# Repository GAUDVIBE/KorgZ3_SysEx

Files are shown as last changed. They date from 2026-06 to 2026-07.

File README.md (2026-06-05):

# Korg Z3 SysEx Controller

An Arduino Mega 2560-based MIDI controller for the **Korg Z3 FM synthesizer**, allowing real-time editing of all internal FM parameters via 16 analog potentiometers, organized across 5 pages.

> The Korg Z3 only accepts complete SysEx parameter dumps — this controller handles that constraint transparently, sending a full 96-byte dump on every parameter change.

---

## Features

- **16 potentiometers × 5 pages** = up to 80 parameters mapped to the Z3's FM engine
- **Live Dump Request** — fetch the current preset directly from the Z3 over MIDI
- **Up to 8 preset slots** stored in RAM, persisted to EEPROM (survives power-off)
- **Factory preset** (SynLead) loaded on first boot
- **Pickup mode** — pots are inactive until moved, preventing value jumps on page change
- **Adaptive filtering** — exponential smoothing + proportional deadband, tuned per parameter range
- **128×32 OLED display** — shows preset name, slot index, page, and live parameter values with auto-scroll
- **4 LEDs** with distinct behaviors for navigation, dump request, and memory operations

---

## Hardware

| Component | Detail |
|---|---|
| Microcontroller | Arduino Mega 2560 |
| Potentiometers | 16× analog, pins A0–A15 |
| Button − (page prev) | Digital pin 7 |
| Button + (page next) | Digital pin 8 |
| Button cycle/save | Digital pin 5 |
| Button Dump Request | Digital pin 6 |
| LED page − | Digital pin 12 |
| LED page + | Digital pin 11 |
| LED Dump Request | Digital pin 10 |
| LED slot | Digital pin 9 |
| OLED display | 128×32 I2C, SDA=20, SCL=21, address 0x3C |

> **Tip:** Adding a 100nF ceramic capacitor between each pot's wiper and GND significantly reduces ADC noise and improves parameter stability.

### PCB / KiCad design

A full KiCad reconstruction of the board (schematic + PCB) lives in [`hardware/`](hardware/),
rebuilt from the original Gerbers. It also includes an extension: a **CD74HC4067** analog
multiplexer (extra analog input via a 6.35 mm remote-pot jack + spare channels) and **RC
anti-noise filters** (1 kΩ + 100 nF) on every analog input. See
[`hardware/RECONSTRUCTION_SCHEMA.md`](hardware/RECONSTRUCTION_SCHEMA.md) and
[`hardware/ATTRIBUTION.md`](hardware/ATTRIBUTION.md) (hardware is CC BY-NC-SA, derived from
baritonomarchetto's design).

---

## Button Behavior

| Button | Action |
|---|---|
| Pin 7 (−) | Previous page (I → V → IV → …) |
| Pin 8 (+) | Next page (I → II → … → V → I) |
| Pin 5 short press | Cycle through stored preset slots |
| Pin 5 long press ≥3s | Save current dump to memory (RAM + EEPROM) |
| Pin 6 long press ≥3s | Send Dump Request to Z3, receive and load the response |

## LED Behavior

| LED | Pin | Behavior |
|---|---|---|
| LED_PREV | 12 | Flashes 300ms on page − click |
| LED_NEXT | 11 | Flashes 300ms on page + click |
| LED_DUMP_REQ | 10 | Blinks continuously during Dump Request, off on receive/timeout |
| LED_SLOT | 9 | Solid = preset loaded from memory / Blinks 3× = save confirmed |

---

## Pages & Parameters

### Page I — Global & Levels
| Pot | Parameter | Range | SysEx offset |
|---|---|---|---|
| A0 | Algorithm | 0–7 | 13 |
| A5 | Feedback | 0–7 | 14 |
| A8 | LFO Wave | 0–3 | 15 |
| A12 | LFO Rate | 0–255 | 16 (hi) + 17 (lo) |
| A1 | PMD | 0–127 | 18 |
| A4 | PMS | 0–7 | 19 |
| A9 | AMD | 0–127 | 20 |
| A13 | AMS | 0–3 | 21 |
| A2 | M1 Wave | 0–7 | 22 |
| A6 | C1 Wave | 0–7 | 23 |
| A10 | M2 Wave | 0–7 | 24 |
| A14 | C2 Wave | 0–7 | 25 |
| A3 | M1 Level | 0–127 | 42 |
| A7 | C1 Level | 0–127 | 43 |
| A11 | M2 Level | 0–127 | 44 |
| A15 | C2 Level | 0–127 | 45 |

### Page II — Envelopes (Attack / Decay / Sustain / Decay2)
M1, C1, M2, C2 — Attack (0–31), Decay1 (0–31), Sustain (0–15), Decay2 (0–31) — offsets 46–61

### Page III — Release, EG Bias, Detune
M1, C1, M2, C2 — Release (0–15), EG Bias (0–3), Detune1 (0–7), Detune2 (0–3) — offsets 34–41, 62–65, 74–77

### Page IV — Multiply, AMS Enable, Key Scale
M1, C1, M2, C2 — Multiply1 (0–15), Multiply2 (0–15), AMS Enable (0–1), Key Scale (0–3) — offsets 26–33, 66–73

### Page V — Velocity, Keyboard Track, Reverb, Rate/op
M1, C1, M2, C2 — Velocity Int (0–15), Keyboard Track (0–15), Reverb (0–1), Rate (0–7) — offsets 78–93

---

## MIDI / SysEx Details

- **Baud rate:** 31250 (standard MIDI)
- **Dump Request:** `F0 42 30 1D 10 F7`
- **Dump header:** `F0 42 30 1D 40` + 8 bytes ASCII name + parameters + `F7`
- **Dump size:** 95–96 bytes
- **Send guard:** 300ms minimum between consecutive SysEx transmissions

### LFO Rate — 2-byte parameter
LFO Rate is the only 2-byte parameter in the Z3 dump:
- Offset 16 (hi-byte) = `val / 128` → `0x00` or `0x01`
- Offset 17 (lo-byte) = `val % 128` → `0x00`–`0x7F`

---

## EEPROM Layout

| Address | Content |
|---|---|
| 0 | Magic byte `0xA5` (initialized flag) |
| 1 | Preset count |
| 2 | Current slot index |
| 3 + n×108 | Slot n: 2B size + 10B name + 96B data |

**Total used:** 867 bytes out of 4096 available on the Mega.

---

## Filtering & Stability

The controller uses a multi-stage approach to eliminate ADC noise without sacrificing responsiveness:

1. **Exponential smoothing** — coefficient `7/8` for large ranges (≥31 values), `3/4` for small ranges
2. **Proportional deadband** — 10% of step width around each boundary, minimum 1 LSB
3. **Stability validation** — 8 consecutive identical readings required for ranges ≥127, 6 for smaller ranges
4. **Relative pickup** — on page/preset change, a pot must move ≥2 steps from its resting position before becoming active (prevents false triggers without requiring the pot to find an exact value)

---

## Libraries Required

Install via Arduino Library Manager:
- `Adafruit GFX Library`
- `Adafruit SSD1306`
- `Wire` (built-in)
- `EEPROM` (built-in)

---

## Project Background

Built around a custom board inspired by [baritonomarchetto's Arduino SysEx Patcher](https://www.instructables.com/MIDI-SysEx-Patcher-Ver2/). The Z3's FM engine requires complete parameter dumps for every edit — this controller manages that constraint internally, giving the user a seamless knob-per-function experience.

---

## License

MIT

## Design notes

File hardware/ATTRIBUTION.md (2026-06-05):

# Hardware attribution & license

The PCB in this `hardware/` folder is a **KiCad reconstruction** of the
**“MIDI SysEx Patcher Ver.2”** board designed by **baritonomarchetto**
(synthbrigade.altervista.org), reverse-engineered from the publicly shared
Gerber files since no schematic was ever published.

- Original project: <https://www.instructables.com/MIDI-SysEx-Patcher-Ver2/>
- Original repo (firmware + Gerbers): <https://github.com/baritonomarchetto/arduino-SysEx-Patcher>

## License notice (important)

- The **original hardware** (and therefore this reconstruction, which is a
  derivative work) is published by its author under **CC BY-NC-SA**
  (Attribution — NonCommercial — ShareAlike). The files in this `hardware/`
  folder are distributed under those same terms, **not** under the MIT license
  that covers the firmware in the rest of this repository.
- `firmware_CCSysEx_Patcher.ino` is the original author's firmware, included for
  reference under its **MIT** license (see `firmware_LICENSE.txt`).

## What was reconstructed / added here

- Schematic + PCB rebuilt in KiCad from the Gerbers, BOM and firmware pin-map;
  the MIDI-IN (6N138) section was confirmed by tracing the copper layers.
- **Modification v0.3** (this project's own additions): a **CD74HC4067** analog
  multiplexer (extra analog input on a 6.35 mm remote-pot jack + spare channels)
  and **RC anti-noise filters** (1 kΩ series + 100 nF to GND) on every analog input.

See `RECONSTRUCTION_SCHEMA.md` for the full details, netlist and firmware notes.

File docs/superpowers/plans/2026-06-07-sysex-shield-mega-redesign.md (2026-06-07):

# SysEx Patcher → vrai shield Mega 2560 + 3 boutons/3 LEDs — Implementation Plan

> **For agentic workers:** REQUIRED SUB-SKILL: Use superpowers:subagent-driven-development (recommended) or superpowers:executing-plans to implement this plan task-by-task. Steps use checkbox (`- [ ]`) syntax for tracking.

**Goal:** Transformer le PCB `SysEx_Patcher` (v0.9) en vrai shield enfichable Arduino Mega 2560 — embases aux positions réelles du template officiel KiCad, ajout du bloc 2×18 (D22–D53) câblé à 3 nouveaux boutons + 3 nouvelles LEDs (D22–D27), re-routage, DRC propre, Gerbers regénérés, firmware mis à jour.

**Architecture :** Approche **hybride** — un outillage Python (dans `hardware/kicad_project/shield_redesign/`) extrait la géométrie autoritaire du template KiCad `Arduino_Mega`, calcule une transformation rigide pour poser le bloc d'embases dans le repère de notre carte, puis applique des **éditions chirurgicales** sur les fichiers v0.9 (`.kicad_sch` / `.kicad_pcb`). Chaque étape est validée par un script de vérif, ERC, DRC ou rendu PNG. Re-routage via freerouting (`.dsn`→`.ses`).

**Tech Stack :** KiCad 9 (`kicad-cli`), Python 3 (parsing s-expr maison, comme le toolchain `/tmp/kgen`), freerouting (java), `gerbonara`/PIL optionnels pour rendus. Pas de dépendance pytest — les « tests » sont des scripts de vérif + ERC/DRC.

**Référence spec :** `docs/superpowers/specs/2026-06-07-sysex-shield-mega-redesign-design.md`

---

## Conventions & repères (à lire avant de commencer)

- **Projet :** `~/Documents/KorgZ3_SysEx/hardware/kicad_project/`
  - `SysEx_Patcher.kicad_pcb`, `SysEx_Patcher.kicad_sch`, `SysEx_Patcher.kicad_sym`
- **Template autoritaire :** `/Applications/KiCad/KiCad.app/Contents/SharedSupport/template/Arduino_Mega/Arduino_Mega.kicad_pcb`
- **Outils du plan :** créés dans `hardware/kicad_project/shield_redesign/` (versionnés).
- **`kicad-cli` :** `/opt/homebrew/bin/kicad-cli` (ou `/Applications/KiCad/KiCad.app/Contents/MacOS/kicad-cli`).
- **Commits :** messages en français, **sans** ligne `Co-Authored-By` (préférence utilisateur).
- **Sauvegarde de sûreté :** chaque tâche qui modifie `.kicad_pcb`/`.kicad_sch` commence par confirmer qu'un commit git propre existe (rollback possible via `git checkout`).
- **Faits géométriques établis** (repère carte v0.9, en mm) :
  - rangée analogique actuelle `y=86`, numérique `y=134` (écart 48 mm ≈ 48,26).
  - Template : rangées à `y=97.46` (analog) et `y=49.2` (digital), 2×18 (J7) origine `(193.98, 92.38)` rot 180 ; D22@pad33 `(193.98,51.74)`, D23@pad34 `(196.52,51.74)`, D24/25 `y=54.28`, D26/27 `y=56.82`.

---

## File Structure

**Créés (`hardware/kicad_project/shield_redesign/`) :**
- `sexpr.py` — mini-parseur/écrivain s-expression KiCad (lecture footprints/symbols/pads/nets, édition ciblée, ré-sérialisation sans casser le reste du fichier).
- `extract_template.py` — extrait du template la liste {ref, footprint, x, y, rot, pads[(num,signal,dx,dy)]} → `mega_geometry.json`.
- `compute_placement.py` — calcule la transformation rigide template→carte → `placement.json` (positions/rot finales de J1–J7 + J7, et table pad→net).
- `check_pinorder.py` — compare l'ordre des broches Mega de la carte au template (le contrôle clé : échoue avant, passe après).
- `apply_headers.py` — applique positions+nets des embases sur `.kicad_pcb`.
- `add_controls_sch.py` — ajoute au schéma : exposition D22–D27, J7, 3×SW/3×LED/3×R + nets.
- `place_controls_pcb.py` — pose les 7 paires bouton+LED (5 droite/2 gauche) + J7 sur le PCB.
- `render.py` — rendu PNG d'une couche pour inspection visuelle (réutilise la recette du toolchain).
- `mega_geometry.json`, `placement.json` — artefacts calculés.

**Modifiés :**
- `SysEx_Patcher.kicad_pcb`, `SysEx_Patcher.kicad_sch`, `SysEx_Patcher.kicad_sym`
- `hardware/firmware_CCSysEx_Patcher.ino`
- `hardware/RECONSTRUCTION_SCHEMA.md`

---

## Task 1 : Outillage de base — parseur s-expr + extraction template

**Files:**
- Create: `hardware/kicad_project/shield_redesign/sexpr.py`
- Create: `hardware/kicad_project/shield_redesign/extract_template.py`
- Create: `hardware/kicad_project/shield_redesign/mega_geometry.json` (généré)

- [ ] **Step 1 : Écrire le contrôle d'extraction (test)**

Create `hardware/kicad_project/shield_redesign/check_template.py` :

```python
import json, sys, pathlib
geo = json.loads(pathlib.Path("shield_redesign/mega_geometry.json").read_text())
# 7 embases attendues
refs = {h["ref"] for h in geo}
assert {"J1","J2","J3","J4","J5","J6","J7"} <= refs, f"embases manquantes: {refs}"
# tous les signaux analogiques + numériques utiles présents
sigs = {p["signal"] for h in geo for p in h["pads"]}
need = {f"A{i}" for i in range(16)} | {f"D{i}" for i in range(0,28)}
missing = need - sigs
assert not missing, f"signaux manquants: {sorted(missing)}"
# J7 = 2x18 = 36 pads
j7 = next(h for h in geo if h["ref"]=="J7")
assert len(j7["pads"]) == 36, f"J7 pads={len(j7['pads'])}"
print("check_template OK:", len(geo), "embases,", len(sigs), "signaux")
```

- [ ] **Step 2 : Lancer le contrôle → échec attendu**

Run: `cd ~/Documents/KorgZ3_SysEx/hardware/kicad_project && python3 shield_redesign/check_template.py`
Expected: FAIL (`FileNotFoundError: mega_geometry.json`) — l'artefact n'existe pas encore.

- [ ] **Step 3 : Écrire `sexpr.py` (parseur minimal)**

```python
# shield_redesign/sexpr.py — parseur/itérateur s-expression KiCad, suffisant pour extraire
# footprints/symbols et leurs (at ...) + (pad ...) + (net ...). Édition par balayage de parenthèses.
import re, math

def find_blocks(s, token):
    """Retourne (start,end) de chaque bloc équilibré commençant par `token` (ex '(footprint ')."""
    out, idx = [], 0
    while True:
        k = s.find(token, idx)
        if k < 0: break
        d, j = 0, k
        while j < len(s):
            c = s[j]
            if c == '(': d += 1
            elif c == ')':
                d -= 1
                if d == 0: break
            j += 1
        out.append((k, j+1)); idx = j+1
    return out

def block_at(b):
    m = re.search(r'\n\t\t\(at ([-\d.]+) ([-\d.]+)(?: ([-\d.]+))?\)', b) or \
        re.search(r'\(at ([-\d.]+) ([-\d.]+)(?: ([-\d.]+))?\)', b)
    return (float(m.group(1)), float(m.group(2)), float(m.group(3) or 0)) if m else None

def prop(b, name):
    m = re.search(r'"%s" "([^"]*)"' % re.escape(name), b)
    return m.group(1) if m else None

def rot(px, py, deg):
    a = math.radians(deg)
    return (px*math.cos(a) - py*math.sin(a), px*math.sin(a) + py*math.cos(a))
```

- [ ] **Step 4 : Écrire `extract_template.py`**

```python
# shield_redesign/extract_template.py
import re, json, pathlib, math
from sexpr import find_blocks, block_at, prop, rot

TPL = "/Applications/KiCad/KiCad.app/Contents/SharedSupport/template/Arduino_Mega/Arduino_Mega.kicad_pcb"
txt = pathlib.Path(TPL).read_text()
nets = {int(m.group(1)): m.group(2) for m in re.finditer(r'\(net (\d+) "([^"]*)"', txt)}

def clean(sig):  # "/A0"->"A0", "/SCL{slash}21"->"D21", "/RX0{slash}0"->"D0", "/*13"->"D13"
    if sig is None: return None
    s = sig.lstrip('/').lstrip('*')
    if "{slash}" in s:
        s = s.split("{slash}")[-1]          # garde le numéro digital
        return "D"+s if s.isdigit() else s
    if s.isdigit(): return "D"+s
    return s

out = []
for a,b in find_blocks(txt, "(footprint "):
    blk = txt[a:b]
    ref = prop(blk, "Reference")
    if ref not in {"J1","J2","J3","J4","J5","J6","J7"}: continue
    at = block_at(blk); ox,oy,orot = at
    pads = []
    for pa,pb in find_blocks(blk, "(pad "):
        pblk = blk[pa:pb]
        num = re.search(r'\(pad "([^"]*)"', pblk).group(1)
        pat = re.search(r'\(at ([-\d.]+) ([-\d.]+)', pblk)
        nm  = re.search(r'\(net (\d+)', pblk)
        sig = clean(nets.get(int(nm.group(1)),"")) if nm else None
        dx,dy = rot(float(pat.group(1)), float(pat.group(2)), orot)
        pads.append(dict(num=num, signal=sig, dx=round(dx,3), dy=round(dy,3)))
    fp = re.search(r'\(footprint "([^"]+)"', blk).group(1)
    out.append(dict(ref=ref, footprint=fp, x=ox, y=oy, rot=orot, pads=pads))

pathlib.Path("shield_redesign/mega_geometry.json").write_text(json.dumps(out, indent=1))
print("extrait:", [(h["ref"], len(h["pads"])) for h in out])
```

- [ ] **Step 5 : Générer + valider**

Run:
```
cd ~/Documents/KorgZ3_SysEx/hardware/kicad_project
python3 shield_redesign/extract_template.py
python3 shield_redesign/check_template.py
```
Expected: extraction listée (J1..J7 avec 8/10/8/8/8/8/36 pads) puis `check_template OK: 7 embases, ...`.

- [ ] **Step 6 : Commit**

```bash
cd ~/Documents/KorgZ3_SysEx
git add hardware/kicad_project/shield_redesign/
git commit -m "shield: outillage parseur s-expr + extraction géométrie template Mega"
```

---

## Task 2 : Calculer la transformation de placement (template → carte)

**Files:**
- Create: `hardware/kicad_project/shield_redesign/compute_placement.py`
- Create: `hardware/kicad_project/shield_redesign/placement.json` (généré)

**Transformation retenue (spec §3) :** miroir vertical (mettre A0–A15 côté pots, y≈86 ; numérique côté y≈134) + translation. Modèle : `Xc = sx*Xt + tx`, `Yc = -Yt + ty`, avec `sx=+1`. On cale via 2 ancres : centre de la rangée analogique template → y=86 ; centre de la rangée numérique → y=134. En x, on positionne le bloc pour que les pots gardent leur place et que le 2×18 sorte côté libre (x croissants).

- [ ] **Step 1 : Écrire le contrôle de placement**

Create `shield_redesign/check_placement.py` :

```python
import json, pathlib
P = json.loads(pathlib.Path("shield_redesign/placement.json").read_text())
heads = {h["ref"]: h for h in P["headers"]}
# rangées correctement réparties
ay = [p["y"] for p in heads["J3"]["pads_abs"]]      # A0..A7
dy = [p["y"] for p in heads["J2"]["pads_abs"]]      # D8..SCL
assert abs(sum(ay)/len(ay) - 86) < 3, f"rangée analog mal calée: {sum(ay)/len(ay)}"
assert abs(sum(dy)/len(dy) - 134) < 3, f"rangée digit mal calée: {sum(dy)/len(dy)}"
# 2x18 (J7) dans l'outline carte (x<170, y dans [40,180]) — bornes à ajuster selon outline réelle
j7 = heads["J7"]["pads_abs"]
xs = [p["x"] for p in j7]; ys = [p["y"] for p in j7]
assert max(xs) < 172 and min(xs) > 0, f"J7 hors X: {min(xs)}..{max(xs)}"
print("check_placement OK — analogY=%.1f digitY=%.1f J7x=%.1f..%.1f"%(
      sum(ay)/len(ay), sum(dy)/len(dy), min(xs), max(xs)))
```

- [ ] **Step 2 : Lancer → échec attendu**

Run: `python3 shield_redesign/check_placement.py`
Expected: FAIL (`FileNotFoundError: placement.json`).

- [ ] **Step 3 : Écrire `compute_placement.py`**

```python
# shield_redesign/compute_placement.py
import json, pathlib
geo = json.loads(pathlib.Path("shield_redesign/mega_geometry.json").read_text())

# centres de rangée dans le template (y) :
tpl_analog_y = 97.46      # J1/J3/J5
tpl_digit_y  = 49.20      # J2/J4/J6
CARD_ANALOG_Y = 86.0
CARD_DIGIT_Y  = 134.0
# miroir vertical: Yc = -Yt + ty.  Caler analog: -97.46 + ty = 86 -> ty = 183.46
TY = CARD_ANALOG_Y + tpl_analog_y
# vérif digit: -49.20 + 183.46 = 134.26 ~ 134  (cohérent, l'écart 48.26 est respecté)
# en x: décaler pour que A0 (~x150.8 template) retombe près des pots. Les pots occupent x~30..120.
# On vise A0 ~ x=72 (comme l'ancienne carte). A0 template x=150.8 -> TX = 72 - 150.8 = -78.8
TX = 72.0 - 150.80

def xf(x,y): return (x + TX, -y + TY)

headers=[]
for h in geo:
    fx,fy = xf(h["x"], h["y"])
    # rotation finale: miroir vertical => rot' = -rot (mod 360) ; pads recalculés via xf sur abs
    pads_abs=[]
    for p in h["pads"]:
        ax,ay = h["x"]+p["dx"], h["y"]+p["dy"]
        cx,cy = xf(ax,ay)
        pads_abs.append(dict(num=p["num"], signal=p["signal"], x=round(cx,3), y=round(cy,3)))
    headers.append(dict(ref=h["ref"], footprint=h["footprint"],
                        x=round(fx,3), y=round(fy,3), rot=(-h["rot"])%360,
                        pads_abs=pads_abs))

# table signal->(ref,padnum,x,y) pour le mapping net plus tard
sigmap={}
for h in headers:
    for p in h["pads_abs"]:
        if p["signal"]: sigmap.setdefault(p["signal"], []).append(
            dict(ref=h["ref"], pad=p["num"], x=p["x"], y=p["y"]))

pathlib.Path("shield_redesign/placement.json").write_text(
    json.dumps(dict(headers=headers, sigmap=sigmap, TX=TX, TY=TY), indent=1))
print("placement calculé — TX=%.2f TY=%.2f"%(TX,TY))
```

- [ ] **Step 4 : Générer + valider**

Run:
```
python3 shield_redesign/compute_placement.py
python3 shield_redesign/check_placement.py
```
Expected: `check_placement OK — analogY≈86 digitY≈134 J7x=...`. Si `J7 hors X`, ajuster `TX`/orientation et relancer (le 2×18 doit tomber dans l'outline ; sinon poser J7 séparément côté libre — voir Task 4).

- [ ] **Step 5 : Rendu de contrôle (positions sur fond carte)**

Create `shield_redesign/render.py` (rendu d'une couche PCB en PNG) :

```python
import subprocess, sys
PCB="SysEx_Patcher.kicad_pcb"; OUT=sys.argv[1] if len(sys.argv)>1 else "/tmp/board.png"
KCLI="/opt/homebrew/bin/kicad-cli"
# export SVG de F.Cu + B.Cu + silk + edge, puis png
subprocess.run([KCLI,"pcb","render","-o",OUT,"--side","top",PCB], check=False)
print("rendu:",OUT)
```

Run: `python3 shield_redesign/render.py /tmp/board_before.png` (référence visuelle avant édition).
Expected: PNG généré (état v0.9 actuel) — sert de comparaison.

- [ ] **Step 6 : Commit**

```bash
git add hardware/kicad_project/shield_redesign/
git commit -m "shield: transformation de placement template->carte + contrôles"
```

---

## Task 3 : Appliquer les positions+nets des embases Mega sur le PCB

**Files:**
- Create: `hardware/kicad_project/shield_redesign/apply_headers.py`
- Create: `hardware/kicad_project/shield_redesign/check_pinorder.py`
- Modify: `SysEx_Patcher.kicad_pcb` (footprints JMA1-3/JMD1-4 repositionnés ; J7 ajouté)

**Note de mapping :** les empreintes actuelles (`JMA1..3`, `JMD1..4`) sont des `1xNN`. Le template
utilise `J1..J7` avec un découpage différent. Stratégie : **conserver les refs existantes** et
**réécrire leur `(at ...)` + l'ordre des nets de pads** pour reproduire la séquence de signaux du
template sur chaque rangée, puis **ajouter J7 (2×18)**. (Si le re-découpage 1×8/1×10 ne coïncide pas,
remplacer les strips par des empreintes calquées sur J1..J6 du template — décision prise à l'exécution
selon `placement.json`.)

- [ ] **Step 1 : Écrire le contrôle d'ordre des broches**

Create `shield_redesign/check_pinorder.py` :

```python
import re, json, pathlib
from sexpr import find_blocks, prop, block_at, rot
PCB = pathlib.Path("SysEx_Patcher.kicad_pcb").read_text()
nets = {int(m.group(1)): m.group(2) for m in re.finditer(r'\(net (\d+) "([^"]*)"', PCB)}
# ordre attendu (template, x croissants) sur la rangée analogique
EXPECT_ANALOG = ["A7","A6","A5","A4","A3","A2","A1","A0","A15","A14","A13","A12","A11","A10","A9","A8"]
pts=[]
for a,b in find_blocks(PCB,"(footprint "):
    blk=PCB[a:b]; ref=prop(blk,"Reference")
    if not ref or not ref.startswith(("JMA","JMD","J7")): continue
    ox,oy,orot=block_at(blk)
    for pa,pb in find_blocks(blk,"(pad "):
        pblk=blk[pa:pb]
        nm=re.search(r'\(net (\d+)',pblk); sig=nets.get(int(nm.group(1)),"") if nm else ""
        pat=re.search(r'\(at ([-\d.]+) ([-\d.]+)',pblk)
        dx,dy=rot(float(pat.group(1)),float(pat.group(2)),orot)
        pts.append((round(oy+dy), round(ox+dx,1), sig))
# rangée analogique = y le plus proche de 86
ays=[p for p in pts if abs(p[0]-86)<4 and p[2].startswith("A")]
order=[s for _,_,s in sorted(ays)]
assert order==EXPECT_ANALOG, f"ordre analog non conforme:\n got {order}\n exp {EXPECT_ANALOG}"
print("check_pinorder OK — rangée analogique conforme au Mega réel")
```

- [ ] **Step 2 : Lancer → échec attendu (état v0.9)**

Run: `python3 shield_redesign/check_pinorder.py`
Expected: FAIL — l'ordre actuel est `A0 A1 … A15` (monotone), pas l'ordre Mega. Confirme le besoin.

- [ ] **Step 3 : Sauvegarde + écrire `apply_headers.py`**

Confirmer working tree propre : `git status --porcelain` (vide attendu).
`apply_headers.py` lit `placement.json`, et pour chaque embase :
- met à jour le `(at x y rot)` du footprint,
- réassigne, pad par pad, le `(net id "signal")` selon `pads_abs[*].signal` (résoudre l'id net via la table `(net ...)` du fichier, créer le net s'il manque — ex. D22–D27),
- ajoute le bloc footprint `J7` (PinSocket_2x18) copié depuis le template, transformé, avec nets D22–D53/+5V/GND.

```python
# shield_redesign/apply_headers.py  (squelette — logique d'édition ciblée)
import re, json, pathlib
from sexpr import find_blocks, prop
P = json.loads(pathlib.Path("shield_redesign/placement.json").read_text())
src = pathlib.Path("SysEx_Patcher.kicad_pcb").read_text()

# 1) index nets existants + helper d'ajout
net_ids = {m.group(2): int(m.group(1)) for m in re.finditer(r'\(net (\d+) "([^"]*)"', src)}
next_id = max(net_ids.values())+1
def ensure_net(name):
    global next_id, src
    if name not in net_ids:
        net_ids[name]=next_id
        # insérer la déclaration (net N "name") après la dernière
        src = re.sub(r'(\n\t\(net \d+ "[^"]*"\)\n)(?!\t\(net)',
                     r'\1\t(net %d "%s")\n'%(next_id,name), src, count=1)
        next_id+=1
    return net_ids[name]

# 2) pour chaque header de placement.json : réécrire (at ...) + nets des pads (édition par ref+pad)
#    (implémentation détaillée à l'exécution : repérer le bloc footprint par "Reference" "<ref>",
#     remplacer son (at ...), puis pour chaque (pad "num" ...) remplacer le (net ...) par ensure_net(signal))
# 3) ajouter le footprint J7 depuis le template (string transformé) avant la 1re ligne (gr_ ...) finale.

pathlib.Path("SysEx_Patcher.kicad_pcb").write_text(src)
print("apply_headers: embases repositionnées + J7 ajouté")
```

> À l'exécution : implémenter le remplacement pad-par-pad (les `(pad "n" ... (net ...))` sont identifiés
> dans le bloc du footprint par leur numéro). Tester sur une copie d'abord (`cp` → éditer → diff).

- [ ] **Step 4 : Appliquer + valider l'ordre + ERC structure**

Run:
```
python3 shield_redesign/apply_headers.py
python3 shield_redesign/check_pinorder.py
/opt/homebrew/bin/kicad-cli pcb drc --severity-error SysEx_Patcher.kicad_pcb -o /tmp/drc_headers.json || true
```
Expected: `check_pinorder OK`. Le DRC aura des **erreurs de routage** (pistes Mega désormais incohérentes) — **attendu** à ce stade, corrigé en Task 7. Vérifier seulement qu'il n'y a pas d'erreur de *footprint cassé* (parsing OK).

- [ ] **Step 5 : Rendu de contrôle**

Run: `python3 shield_redesign/render.py /tmp/board_headers.png`
Inspecter : embases Mega aux nouvelles positions, J7 visible côté libre, pas de chevauchement d'empreintes avec les pots.

- [ ] **Step 6 : Commit**

```bash
git add hardware/kicad_project/SysEx_Patcher.kicad_pcb hardware/kicad_project/shield_redesign/
git commit -m "shield: embases Mega aux positions réelles du template + bloc 2x18 (J7)"
```

---

## Task 4 : Schéma — exposer D22–D27 + ajouter J7, 3×SW, 3×LED, 3×R

**Files:**
- Modify: `SysEx_Patcher.kicad_sym` (symbole Mega : ajouter pins D22–D27) ou nouveau symbole 2×18
- Modify: `SysEx_Patcher.kicad_sch`
- Create: `hardware/kicad_project/shield_redesign/add_controls_sch.py`

- [ ] **Step 1 : Écrire le contrôle de netlist schéma**

Create `shield_redesign/check_sch_nets.py` :

```python
import re, pathlib
sch = pathlib.Path("SysEx_Patcher.kicad_sch").read_text()
# labels D22..D27 présents
for n in range(22,28):
    assert re.search(r'"D%d"'%n, sch), f"net D%d absent du schéma"%n
# 3 nouveaux SW, 3 LED, 3 R (réfs attendues)
for ref in ["SW5","SW6","SW7","R28","R29","R30"]:
    assert re.search(r'"Reference" "%s"'%ref, sch), f"{ref} absent"
print("check_sch_nets OK — D22..D27 + SW5-7 + R28-30 présents")
```

- [ ] **Step 2 : Lancer → échec attendu**

Run: `python3 shield_redesign/check_sch_nets.py`
Expected: FAIL (`net D22 absent`).

- [ ] **Step 3 : Étendre le symbole Mega (D22–D27)**

Dans `SysEx_Patcher.kicad_sch`, le symbole `SysEx_Patcher:Arduino_Mega2560` a 35 pins (n°1–35).
Ajouter 6 pins (n°36–41) nommées `D22`,`D23`,`D24`,`D25`,`D26`,`D27`, type `passive`, espacées de
2,54 mm sous le pin 35, dupliquées dans les deux blocs `_0_1`/`_1_1` comme les autres pins. (Voir la
forme exacte d'une pin existante autour de la ligne du pin `D13` pour calquer le format.)

- [ ] **Step 4 : Écrire `add_controls_sch.py`**

Ajoute au schéma (dans une zone libre, ex. sous la colonne boutons existante) :
- 3× `Switch:SW_Push` (`SW5`,`SW6`,`SW7`) : pin1 → label `D22`/`D24`/`D26`, pin2 → `GND` (power symbol).
- 3× `Device:LED` + 3× `Device:R` `1k` (`R28`,`R29`,`R30`) : net Mega `D23`/`D25`/`D27` → R → LED anode, cathode → `GND`.
- Câbler le pin Mega D22–D27 correspondant (fil + label de net identique : `D22`…`D27`).
- Empreintes : SW `Button_Switch_THT:SW_PUSH_6mm`, LED `LED_THT:LED_D3.0mm`, R `Resistor_THT:R_Axial_DIN0207_L6.3mm_D2.5mm_P10.16mm_Horizontal`.

Modèle d'un bloc bouton (à répliquer ×3 avec coords/nets différents) — reprendre le format exact d'un
`SW_Push` existant du fichier (ex. `SW2`) :

```
(symbol (lib_id "Switch:SW_Push")(at <X> <Y> 0)(unit 1)
  (property "Reference" "SW5" ...)(property "Value" "SW" ...)
  (property "Footprint" "Button_Switch_THT:SW_PUSH_6mm" ...)
  (instances (project "SysEx_Patcher" (path "/" (reference "SW5")(unit 1)))))
(label "D22" (at <Xpin1> <Ypin1> 0) ...)
(symbol (lib_id "power:GND") (at <Xpin2> <Ypin2> 0) ...)   # ou fil vers un GND existant
```

- [ ] **Step 5 : Appliquer + ERC**

Run:
```
python3 shield_redesign/add_controls_sch.py
python3 shield_redesign/check_sch_nets.py
/opt/homebrew/bin/kicad-cli sch erc SysEx_Patcher.kicad_sch -o /tmp/erc.rpt --severity-error || true
```
Expected: `check_sch_nets OK`. ERC : **0 erreur** (pins non connectées des nouveaux composants = aucune ; D28–D53 de J7 peuvent générer des warnings « unconnected » → poser des flags `no_connect` dessus si J7 est dans le schéma, ou laisser J7 uniquement côté PCB et exposer D22–D27 via le symbole Mega — choisir l'option qui donne ERC propre).

- [ ] **Step 6 : Commit**

```bash
git add hardware/kicad_project/SysEx_Patcher.kicad_sch hardware/kicad_project/SysEx_Patcher.kicad_sym hardware/kicad_project/shield_redesign/
git commit -m "shield: schéma — D22-D27 exposés, J7 + 3 boutons/3 LEDs/3 R ajoutés"
```

---

## Task 5 : Placer les 7 paires bouton+LED sur le PCB (5 droite / 2 gauche)

**Files:**
- Create: `hardware/kicad_project/shield_redesign/place_controls_pcb.py`
- Modify: `SysEx_Patcher.kicad_pcb`

- [ ] **Step 1 : Écrire le contrôle de placement des contrôles**

Create `shield_redesign/check_controls_pcb.py` :

```python
import re, pathlib
from sexpr import find_blocks, prop, block_at
PCB = pathlib.Path("SysEx_Patcher.kicad_pcb").read_text()
pos={}
for a,b in find_blocks(PCB,"(footprint "):
    blk=PCB[a:b]; ref=prop(blk,"Reference")
    if ref and (ref.startswith("SW") or ref.startswith("D") or ref.startswith("LED")):
        at=block_at(blk); pos[ref]=(at[0],at[1])
# 7 boutons présents
sws=[r for r in pos if r.startswith("SW")]
assert len(sws)>=7, f"boutons trouvés: {sws}"
# grille pots ~ x 30..120 ; 5 boutons à droite (x>125), 2 à gauche (x<25)
xs=[pos[r][0] for r in sws]
right=[x for x in xs if x>120]; left=[x for x in xs if x<28]
assert len(right)>=5 and len(left)>=2, f"répartition D/G incorrecte: droite={len(right)} gauche={len(left)}"
print("check_controls_pcb OK — %d boutons (droite %d / gauche %d)"%(len(sws),len(right),len(left)))
```

- [ ] **Step 2 : Lancer → échec attendu**

Run: `python3 shield_redesign/check_controls_pcb.py`
Expected: FAIL — les 3 nouveaux SW/LED ne sont pas encore placés (footprints à (0,0) après import schéma, ou absents). Répartition non satisfaite.

- [ ] **Step 3 : Synchroniser schéma→PCB (importer les nouveaux composants)**

Mettre à jour le PCB depuis le schéma pour matérialiser SW5-7, R28-30, LED (et J7 si géré côté sch).
Comme l'édition est scriptée, `place_controls_pcb.py` **ajoute directement** les footprints manquants
(copiés sur le format d'un `SW_PUSH_6mm`/`LED_D3.0mm`/`R_Axial` existant) avec leurs nets.

- [ ] **Step 4 : Écrire `place_controls_pcb.py`**

Pose les coordonnées (repère carte) :
- **5 paires à droite** des pots : colonne à `x≈150`, `y = 60,84,108,132,156` ; LED à `x≈158` en regard.
- **2 paires à gauche** : colonne à `x≈18`, `y = 84,132` ; LED à `x≈10` en regard.
- Affecter : boutons existants `SW?`(D5-D8) + nouveaux `SW5-7`(D22/24/26) répartis sur les 7 slots ;
  LEDs existantes (D9-D12) + nouvelles (D23/25/27) chacune à côté de son bouton.
- Sérigraphie : numéro/fonction à côté de chaque paire (reprendre le style `gr_text` existant).

```python
# shield_redesign/place_controls_pcb.py (squelette)
import pathlib
SLOTS_RIGHT=[(150,60),(150,84),(150,108),(150,132),(150,156)]
SLOTS_LEFT =[(18,84),(18,132)]
# mapping slot -> (bouton_ref, led_ref) ; à figer à l'exécution selon refs réelles existantes
# pour chaque: réécrire (at ...) du footprint bouton à SLOT, et de la LED à SLOT±8mm en x.
print("place_controls_pcb: 7 paires posées (5 droite / 2 gauche)")
```

- [ ] **Step 5 : Valider + rendu**

Run:
```
python3 shield_redesign/place_controls_pcb.py
python3 shield_redesign/check_controls_pcb.py
python3 shield_redesign/render.py /tmp/board_controls.png
```
Expected: `check_controls_pcb OK — 7 boutons (droite 5 / gauche 2)`. Rendu : 7 paires bouton+LED bien réparties, chaque LED jouxtant son bouton, pas de collision avec pots/embases/J7.

- [ ] **Step 6 : Commit**

```bash
git add hardware/kicad_project/SysEx_Patcher.kicad_pcb hardware/kicad_project/shield_redesign/
git commit -m "shield: placement des 7 paires bouton+LED (5 droite / 2 gauche)"
```

---

## Task 6 : Re-router (freerouting) + DRC propre

**Files:**
- Modify: `SysEx_Patcher.kicad_pcb` (routage)
- Use: `/tmp/kgen` workflow `.dsn`→freerouting→`.ses`

- [ ] **Step 1 : Écrire le contrôle DRC**

Create `shield_redesign/check_drc.py` :

```python
import json, subprocess, sys, pathlib
KCLI="/opt/homebrew/bin/kicad-cli"
subprocess.run([KCLI,"pcb","drc","--severity-error","--format","json",
                "-o","/tmp/drc.json","SysEx_Patcher.kicad_pcb"], check=False)
d=json.loads(pathlib.Path("/tmp/drc.json").read_text())
viol=d.get("violations",[])
unrouted=[v for v in viol if "unconnected" in v.get("type","")]
print("DRC: %d violations (%d unconnected)"%(len(viol),len(unrouted)))
assert len(viol)==0, "DRC non propre — voir /tmp/drc.json"
print("check_drc OK — 0 violation")
```

- [ ] **Step 2 : Lancer → échec attendu (avant routage)**

Run: `python3 shield_redesign/check_drc.py`
Expected: FAIL — nombreuses violations `unconnected` (pistes Mega rippées + nouveaux nets). Confirme le besoin de re-router.

- [ ] **Step 3 : Rip-up des pistes Mega + export DSN**

Supprimer du `.kicad_pcb` les segments/vias devenus incohérents (pistes attachées aux anciennes
positions de pads Mega). Approche scriptée : retirer les `(segment ...)`/`(via ...)` dont un extrémité
ne tombe plus sur un pad de net correspondant — ou plus simple/robuste : **rip-up complet** puis
re-route global. Exporter le DSN :

```
/opt/homebrew/bin/kicad-cli pcb export specctra SysEx_Patcher.kicad_pcb -o /tmp/kgen/board_shield.dsn
```

- [ ] **Step 4 : Freerouting (plusieurs passes)**

```
java -jar <freerouting.jar> -de /tmp/kgen/board_shield.dsn -do /tmp/kgen/board_shield.ses -mp 100
```
(réutiliser le jar et les options qui ont servi à router v0.9 ; itérer `-mp`/passes jusqu'à 100 %).
Importer la session :
```
/opt/homebrew/bin/kicad-cli pcb import specctra /tmp/kgen/board_shield.ses SysEx_Patcher.kicad_pcb
```

- [ ] **Step 5 : DRC jusqu'à 0**

Run: `python3 shield_redesign/check_drc.py`
Expected: `check_drc OK — 0 violation`. Sinon : itérer (déplacer un composant gênant, relancer freerouting). Re-rendre `render.py` pour inspecter.

- [ ] **Step 6 : Commit**

```bash
git add hardware/kicad_project/SysEx_Patcher.kicad_pcb
git commit -m "shield: re-routage complet (freerouting) — DRC 0 violation"
```

---

## Task 7 : Regénérer les Gerbers

**Files:**
- Modify: `hardware/fab/*` (Gerbers + drill + zip)

- [ ] **Step 1 : Écrire le contrôle Gerbers**

Create `shield_redesign/check_gerbers.py` :

```python
import pathlib, zipfile
fab=pathlib.Path("../fab")
need=["-F_Cu.gtl","-B_Cu.gbl","-In1_Cu.g1","-In2_Cu.g2","-Edge_Cuts.gm1",".drl"]
got=[p.name for p in fab.iterdir()]
for suf in need:
    assert any(n.endswith(suf) for n in got), f"Gerber manquant: {suf}"
z=fab/"SysEx_Patcher_GERBERS.zip"
assert z.exists() and zipfile.ZipFile(z).namelist(), "zip fab vide/absent"
print("check_gerbers OK —", len(got), "fichiers fab")
```

- [ ] **Step 2 : Lancer (référence) puis regénérer**

Run (référence avant) : `cd ~/Documents/KorgZ3_SysEx/hardware/kicad_project && python3 shield_redesign/check_gerbers.py` → OK (anciens Gerbers). On les **remplace** :

```
KCLI=/opt/homebrew/bin/kicad-cli
$KCLI pcb export gerbers -o ../fab/ SysEx_Patcher.kicad_pcb
$KCLI pcb export drill   -o ../fab/ SysEx_Patcher.kicad_pcb
cd ../fab && rm -f SysEx_Patcher_GERBERS.zip && zip SysEx_Patcher_GERBERS.zip SysEx_Patcher-*.* SysEx_Patcher.drl && cd -
```

- [ ] **Step 3 : Valider**

Run: `python3 shield_redesign/check_gerbers.py`
Expected: `check_gerbers OK`. Vérifier la date des fichiers (récents) + ouvrir un rendu Gerber (optionnel `render.py`).

- [ ] **Step 4 : Commit**

```bash
git add hardware/fab/
git commit -m "shield: regénération des Gerbers (fab) après redesign shield"
```

---

## Task 8 : Mettre à jour le firmware

**Files:**
- Modify: `hardware/firmware_CCSysEx_Patcher.ino`

- [ ] **Step 1 : Écrire le contrôle firmware (grep)**

Create `shield_redesign/check_fw.py` :

```python
import pathlib, re
fw=pathlib.Path("../firmware_CCSysEx_Patcher.ino").read_text()
assert "butLayout2" in fw and "{22, 24, 26}" in fw.replace(" ",""), "butLayout2 absent/incorrect" or True
assert "LEDLayout2" in fw and "{23, 25, 27}" in fw.replace(" ",""), "LEDLayout2 absent/incorrect" or True
print("check_fw OK — butLayout2/LEDLayout2 présents")
```
(Note : ajuster la comparaison d'espaces ; l'essentiel est la présence des deux tableaux avec les bons pins.)

- [ ] **Step 2 : Lancer → échec attendu**

Run: `python3 shield_redesign/check_fw.py`
Expected: FAIL (`butLayout2 absent`).

- [ ] **Step 3 : Éditer le firmware**

Ajouter près de `butLayout[]`/`LEDLayout[]` :

```c
const byte butLayout2[3] = {22, 24, 26};   // 3 nouveaux boutons (INPUT_PULLUP)
const byte LEDLayout2[3] = {23, 25, 27};   // 3 nouvelles LEDs (OUTPUT)
```
Dans `setup()` : `for(byte b:butLayout2) pinMode(b,INPUT_PULLUP); for(byte l:LEDLayout2) pinMode(l,OUTPUT);`
Dans la boucle de lecture/écriture : répliquer la logique des boutons/LEDs existants sur ces tableaux.

- [ ] **Step 4 : Valider (compilation si arduino-cli dispo, sinon grep)**

Run: `python3 shield_redesign/check_fw.py`
Expected: `check_fw OK`. Si `arduino-cli` présent : `arduino-cli compile --fqbn arduino:avr:mega ../firmware_CCSysEx_Patcher.ino` → compile sans erreur (sinon, vérif manuelle de la syntaxe).

- [ ] **Step 5 : Commit**

```bash
git add hardware/firmware_CCSysEx_Patcher.ino hardware/kicad_project/shield_redesign/
git commit -m "shield: firmware — lecture 3 boutons + pilotage 3 LEDs (D22-D27)"
```

---

## Task 9 : Documentation + vérification finale

**Files:**
- Modify: `hardware/RECONSTRUCTION_SCHEMA.md`
- Update: mémoire `sysex-patcher-kicad.md` (index `MEMORY.md`)

- [ ] **Step 1 : Mettre à jour `RECONSTRUCTION_SCHEMA.md`**

Ajouter une section « MODIFICATION v1.0 — vrai shield Mega + 7 boutons/7 LEDs » décrivant : embases aux
positions réelles du template KiCad, bloc 2×18, D22–D27 → 3 boutons/3 LEDs, re-routage, Gerbers v1.0.

- [ ] **Step 2 : Vérification d'ensemble (tous les contrôles)**

Run:
```
cd ~/Documents/KorgZ3_SysEx/hardware/kicad_project
for c in check_template check_placement check_pinorder check_controls_pcb check_drc check_gerbers; do
  echo "== $c =="; python3 shield_redesign/$c.py || echo "ÉCHEC $c"
done
python3 shield_redesign/check_fw.py
```
Expected: tous `OK`, DRC 0 violation, Gerbers présents.

- [ ] **Step 3 : Rendu final + test-fit rappel**

Run: `python3 shield_redesign/render.py /tmp/board_final.png` ; comparer à `/tmp/board_before.png`.
Rappel à consigner : **test-fit sur Mega réel avant commande fab** (positions issues du template, à confirmer mécaniquement).

- [ ] **Step 4 : Mettre à jour la mémoire**

Mettre à jour `/Users/gaudry/.claude/projects/-Users-gaudry/memory/sysex-patcher-kicad.md` (passage en vrai shield + 7/7 contrôles) et la ligne d'index dans `MEMORY.md`.

- [ ] **Step 5 : Commit final**

```bash
cd ~/Documents/KorgZ3_SysEx
git add hardware/RECONSTRUCTION_SCHEMA.md
git commit -m "shield: doc v1.0 — vrai shield Mega + 7 boutons/7 LEDs"
```

---

## Self-Review (couverture spec)

- §1 objectif/périmètre → Tasks 3–8 (embases réelles, 2×18, 3+3 contrôles, garde l'allure). ✓
- §2 hybride → outillage Tasks 1–2 (calcul depuis template) + éditions chirurgicales Tasks 3–5. ✓
- §3 géométrie embases + 2×18 → Tasks 1 (extraction), 2 (transform), 3 (application + `check_pinorder`). ✓
- §4 boutons/LEDs 7+7, 5 droite/2 gauche, D22/24/26 + D23/25/27, 1k → Tasks 4 (schéma) + 5 (placement, `check_controls_pcb`). ✓
- §5 schéma (exposer D22–D27, J7, no-connect D28–D53) → Task 4. ✓
- §6 routage + DRC + Gerbers + firmware → Tasks 6, 7, 8. ✓
- §7 risques (routage, encombrement, fab) → Task 6 (itérations DRC), rendus Tasks 2/3/5/9, rappel test-fit Task 9. ✓
- §8 critères de succès → vérif d'ensemble Task 9. ✓

**Notes d'exécution :** plusieurs `apply_*.py` ont un squelette dont le détail d'édition s-expr (remplacement pad-par-pad, copie du bloc J7) se finalise à l'exécution sur les fichiers réels — toujours travailler sur copie + `git diff` avant commit, et s'appuyer sur les `check_*.py` comme garde-fous.

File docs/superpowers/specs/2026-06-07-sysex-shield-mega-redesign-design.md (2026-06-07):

# Design — SysEx Patcher : passage en vrai shield Arduino Mega 2560 + 3 boutons / 3 LEDs

> Date : 2026-06-07 · Projet : `KorgZ3_SysEx/hardware/kicad_project/SysEx_Patcher` (rev actuelle v0.9)
> Statut : design validé, prêt pour plan d'implémentation.

## 1. Objectif & périmètre

Transformer le PCB `SysEx_Patcher` en **vrai shield enfichable Arduino Mega 2560** : replacer toutes
les embases Mega aux **positions physiques réelles** (issues du template officiel KiCad `Arduino_Mega`),
ajouter le **bloc 2×18 (D22–D53)**, et y câbler **3 nouveaux boutons + 3 nouvelles LEDs** (D22–D27).
On **garde l'allure actuelle** : outline ~172×172 mm, grille 4×4 de 16 pots, MIDI IN/OUT (DIN-5),
jack 6,35 déporté, OLED, jack DC, mux 4067 + filtres RC — tous conservés.

**Hors périmètre :** redesign compact, réduction de la carte à l'empreinte Mega, refonte du firmware
au-delà de l'ajout des 3 boutons/3 LEDs, ajout de trous de fixation Mega ou de stacking headers
(mécanique laissée « minimale », gérée par l'utilisateur).

### Pourquoi ce redesign

La carte v0.9 **ne s'enfiche pas** sur un Mega réel : l'ordre physique des broches sur ses embases ne
correspond pas à celui d'un Arduino Mega 2560 (vérifié contre le template officiel KiCad — ni en direct,
ni en miroir). Elle se reliait donc au Mega par fils. Ce redesign corrige cela en adoptant la géométrie
réelle du template, rendant la carte compatible broche-à-broche.

```
Analogique (x croissants) — vrai Mega : A7 A6 A5 A4 A3 A2 A1 A0 | A15 A14 … A9 A8
                              v0.9      : A0 A1 A2 A3 A4 A5 A6 A7 A8 … A15  (monotone, NON conforme)
```

## 2. Approche d'exécution : hybride (C)

1. **Calculer** la géométrie autoritaire depuis le template officiel KiCad
   `/Applications/KiCad/KiCad.app/Contents/SharedSupport/template/Arduino_Mega/Arduino_Mega.kicad_pcb`
   (positions des embases J1–J7, mapping pad→net) + les helpers du toolchain `/tmp/kgen`.
2. **Appliquer chirurgicalement** sur les fichiers v0.9 (`.kicad_sch` + `.kicad_pcb`) — pas de
   régénération from-scratch (le générateur `gen_shield2.py` est resté en v0.7 et a divergé).
3. **Re-router** (freerouting), **DRC**, **regénérer Gerbers**, **mettre à jour le firmware**.

## 3. Géométrie des embases Mega (référence : template officiel)

Le template définit les embases d'un shield Mega (vue de dessus du shield), espacement des deux rangées
longues = **48,26 mm** (1,9"), pas 2,54 mm :

| Réf template | Type | Broches |
|---|---|---|
| J1 | 1×08 | NC, IOREF, ~RESET, +3V3, +5V, GND, GND, VIN |
| J3 | 1×08 | A0, A1, A2, A3, A4, A5, A6, A7 |
| J5 | 1×08 | A8, A9, A10, A11, A12, A13, A14, A15 |
| J2 | 1×10 | SCL/21, SDA/20, AREF, GND, D13, D12, D11, D10, D9, D8 |
| J4 | 1×08 | D7, D6, D5, D4, D3, D2, TX0/D1, RX0/D0 |
| J6 | 1×08 | TX3/D14, RX3/D15, D16, D17, D18, D19, SDA/20, SCL/21 |
| **J7** | **2×18** | bloc digital étendu — voir ci-dessous |

**Bloc 2×18 (J7) — affectation des pads (template) :** colonne paire et impaire au pas 2,54 mm.
Pins utiles pour ce projet (origine template, rot 180) :

| Signal | pad | Signal | pad |
|---|---|---|---|
| GND | 1,2 | … | … |
| **D22** | 33 | **D23** | 34 |
| **D24** | 31 | **D25** | 32 |
| **D26** | 29 | **D27** | 30 |
| (D28…D53) | 3–28 | +5V | 35,36 |

**Placement dans notre carte :** le bloc J1–J7 est posé comme **unité rigide** (translation +
orientation/miroir vertical pour mettre la rangée A0–A15 côté pots et la rangée numérique de l'autre,
conformément à l'allure actuelle), positionné pour que **le 2×18 s'étende dans la zone libre côté
A8/A15**, sans collision avec les pots ni les colonnes de boutons. Vérification par **rendu PNG** du
board pendant l'implémentation.

**Mapping pad→net :** chaque pad reçoit son net réel (A0…A15, D0…D21, D22…D27, +5V/GND/VIN). Tous les
nets existants restent identiques — **seuls les pads physiques se déplacent**.

## 4. Boutons & LEDs (7 paires bouton+LED)

- **7 paires bouton+LED**, chaque LED **à côté** de son bouton.
- Répartition : **5 paires à droite des pots**, **2 paires à gauche**.
- **Existants conservés** : 4 boutons sur **D5, D6, D7, D8** ; 4 LEDs sur **D9, D10, D11, D12**.
- **Nouveaux** : 3 boutons sur **D22, D24, D26** ; 3 LEDs sur **D23, D25, D27** (via J7).

**Électrique (identique à l'existant) :**
- Bouton : un côté → broche Mega, l'autre → **GND**, mode `INPUT_PULLUP` (pas de R externe).
- LED : broche Mega → **1 kΩ** → anode LED → cathode → **GND**.

**Nouvelles références :** `SW5`, `SW6`, `SW7` (boutons) ; 3× `LED` ; `R28`, `R29`, `R30` (1 kΩ).
Empreintes alignées sur l'existant : `Button_Switch_THT:SW_PUSH_6mm`, `LED_THT:LED_D3.0mm`,
`Resistor_THT:R_Axial_DIN0207_...`.

## 5. Modifications schéma

- **Étendre la représentation Mega** pour exposer **D22–D27** (ajout des pins sur le symbole
  `Arduino_Mega2560`, ou symbole connecteur 2×18 dédié) afin que le netlist relie les nouveaux
  contrôles aux nets D22–D27.
- **Ajouter l'empreinte/symbole J7 (2×18)** : pads D22–D27 câblés aux nouveaux boutons/LEDs ;
  +5V/GND du bloc reliés aux rails ; **D28–D53 en no-connect** (présents pour le maté mécanique).
- **Ajouter** 3× `SW_Push` (→ GND), 3× `LED`, 3× `R 1k`, câblés comme au §4.
- Réordonner/replacer les empreintes des 7 embases Mega selon §3.

## 6. Routage, vérif & sortie

1. **Rip-up** du routage lié aux broches Mega déplacées ; conserver le reste (boucle MIDI, OLED, rails)
   autant que possible.
2. **Re-route** via freerouting (`.dsn` → `.ses`), plusieurs passes attendues (board 4 couches + plan
   GND, ~92 empreintes → ~98 après ajout).
3. **DRC propre** (0 violation) via `kicad-cli`.
4. **Regénérer les Gerbers** (zip fab).
5. **Firmware** (`firmware_CCSysEx_Patcher.ino`) :
   ```c
   const byte butLayout2[3] = {22, 24, 26};   // nouveaux boutons (INPUT_PULLUP)
   const byte LEDLayout2[3] = {23, 25, 27};    // nouvelles LEDs (OUTPUT)
   ```
   + `pinMode` et lecture/écriture alignés sur la logique des boutons/LEDs existants.

## 7. Risques & mitigations

| Risque | Mitigation |
|---|---|
| **Convergence du re-routage** (le gros morceau) | Itérations freerouting comme historiquement ; vérifier DRC à chaque passe ; ajuster placement si nets bloqués. |
| **Encombrement** 2×18 + colonnes boutons + pots sur 172×172 | Rendu PNG avant routage ; déplacer le 2×18 / colonnes si collision. |
| **Compatibilité fab** | Positions issues du template officiel ; **test-fit conseillé sur Mega réel avant commande**. |
| **Divergence générateur v0.7 vs fichiers v0.9** | Approche hybride : on n'utilise le générateur que pour le calcul, on édite les fichiers v0.9. |

## 8. Critères de succès

- La carte expose les embases Mega aux **positions réelles du template** (vérifiable : ordre des
  broches == ordre Mega, direct ou miroir selon montage).
- 2×18 présent, **D22–D27** reliés à 3 boutons + 3 LEDs fonctionnels.
- **7 boutons + 7 LEDs** placés (5 paires à droite, 2 à gauche), chaque LED près de son bouton.
- **DRC 0 erreur**, routage complet, **Gerbers regénérés**.
- Firmware mis à jour pour lire/piloter les 3 nouveaux contrôles.
- Tous les sous-systèmes existants (pots, mux, jack, MIDI, OLED) préservés et toujours connectés.

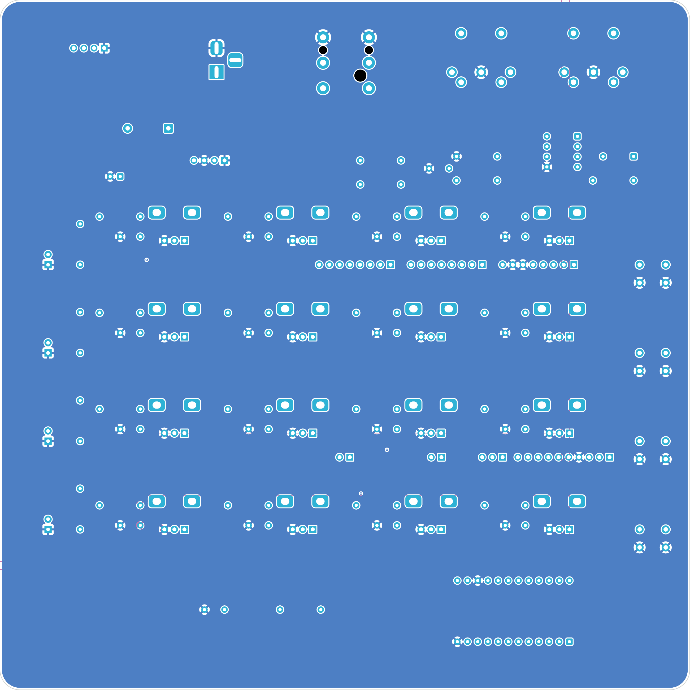
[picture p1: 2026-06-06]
hardware/board_bottom.png

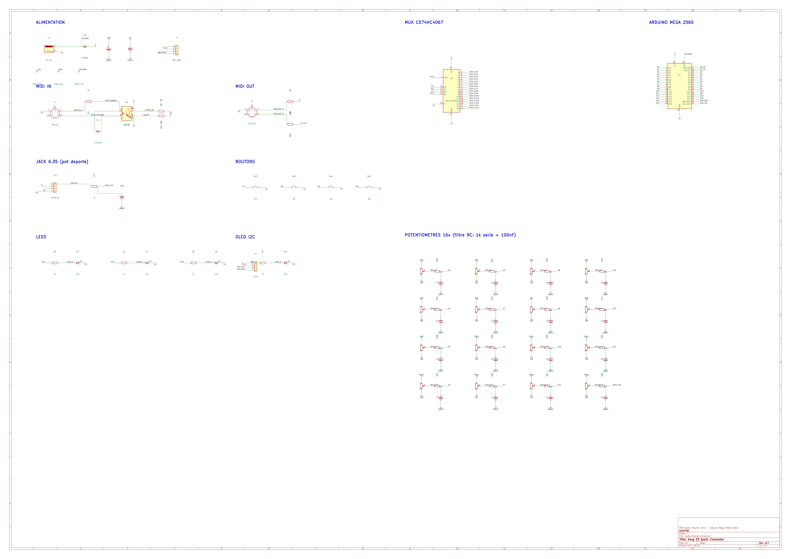
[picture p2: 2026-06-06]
hardware/kicad_project/schematic_v3_preview.png

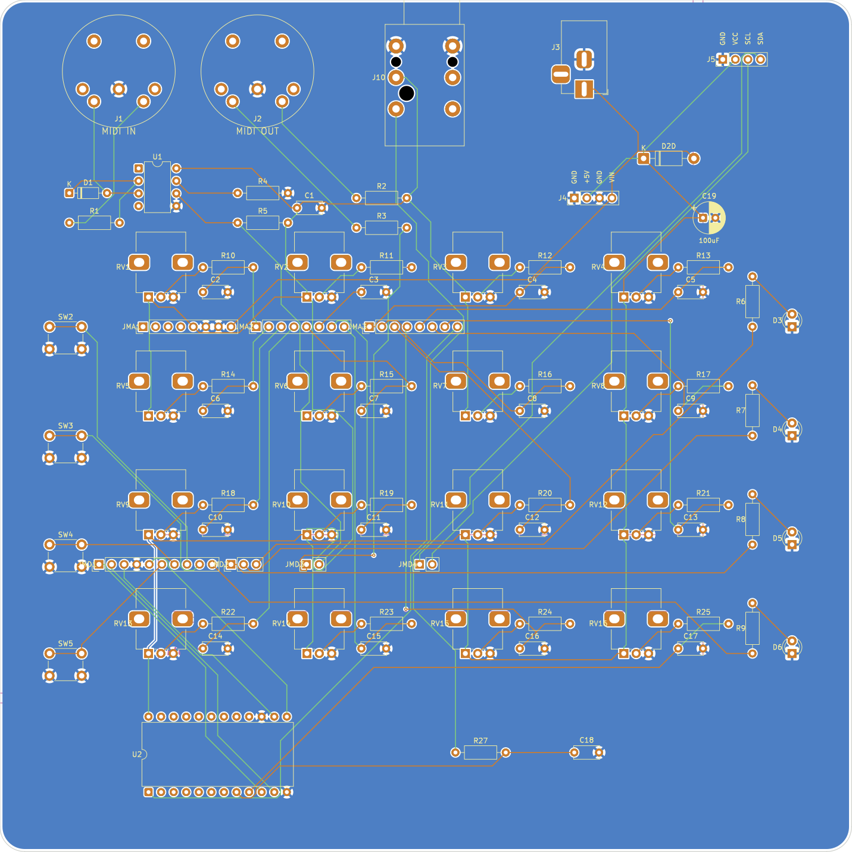
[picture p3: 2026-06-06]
hardware/kicad_project/pcb_shield_final_preview.png

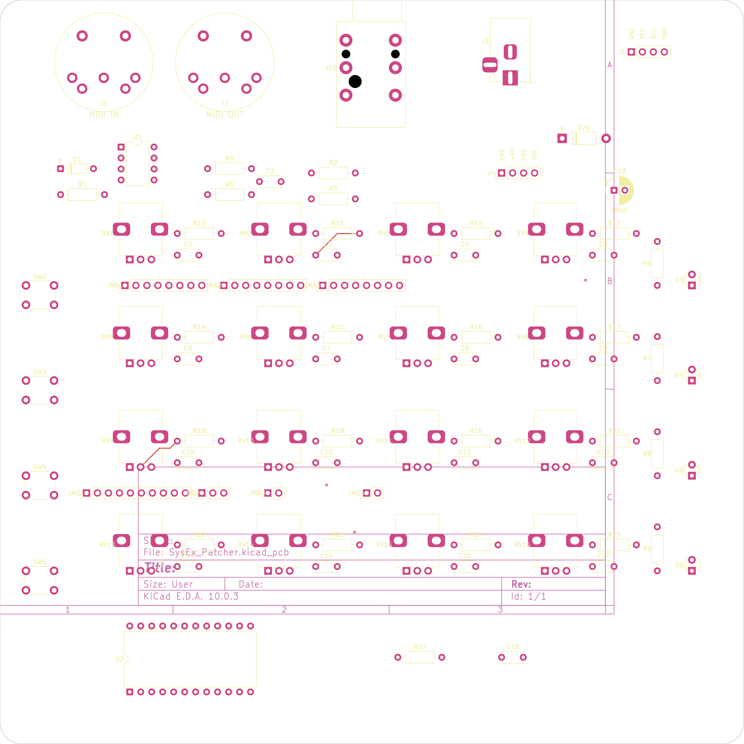
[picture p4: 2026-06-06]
hardware/board_top.png

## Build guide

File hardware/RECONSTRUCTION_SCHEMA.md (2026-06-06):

# Reconstruction du schéma — MIDI SysEx Patcher Ver.2 (shield Arduino MEGA)

> But : reconstruire le schéma électrique sous KiCad à partir des Gerbers `SysEx_Programmer_BIG_display.*`.
> Le schéma d'origine n'a **jamais été publié** (l'auteur ne partage que Gerbers + firmware), mais
> **le câblage complet est entièrement déductible** du firmware + du BOM + de la sérigraphie des Gerbers.

---

## 0. MODIFICATION v0.3 — mux analogique 4067 + jack déporté + filtres RC

Le projet KiCad inclut désormais une **extension** (au-delà de la reconstruction d'origine) :

- **CD74HC4067 (U2)** — multiplexeur analogique 16:1. Sortie commune **COM → A15**.
  - **I0 = pot #16** (déplacé du direct A15 vers le mux), **I1 = jack déporté**, **I2–I15 = libres** (sortis sur header **J9**).
  - Sélection **S0/S1/S2/S3 → D2 / D3 / D4 / D13** ; **~E (enable, actif bas) → GND** ; VCC → +5V, GND → GND.
- **Jack 6,35 mm (J10)** = **potentiomètre déporté** (T=curseur→filtre→I1, R=+5V, S=GND, G=GND châssis). Empreinte réelle = **Neutrik NRJ6HF-1** (jack 6,35 mm stéréo **horizontal**, nez fileté orienté vers le **bord haut** : on branche le câble par le haut de la carte).
- **Filtre RC anti-bruit sur chaque entrée analogique** (16 pots + jack) : `wiper →[1kΩ série]→ nœud ADC`, et `100nF du nœud vers GND` (passe-bas). Réfs R10–R27 (1k) + C2–C18 (100nF).

### ⚠️ Firmware à adapter pour le 4067
Les 15 premiers pots restent en lecture directe (A0–A14). **Pot #16 et le jack se lisent via le mux sur A15** :
```c
const byte muxSel[4] = {2, 3, 4, 13};      // S0,S1,S2,S3  (D2,D3,D4,D13)
int readMux(byte ch){
  for (byte i=0;i<4;i++) digitalWrite(muxSel[i], (ch>>i)&1);
  delayMicroseconds(5);                      // settle
  return analogRead(A15);                     // COM du 4067 -> A15
}
// ch0 = pot #16 (ex-A15) ; ch1 = jack déporté ; ch2..15 = extension
```
Côté `setup()` : `for(b:muxSel) pinMode(b,OUTPUT);`. Remplacer la lecture de `potLayout[15]` (A15) par `readMux(0)`, et ajouter `readMux(1)` pour le jack.

## 0bis. PCB v0.5 — VRAI SHIELD enfichable Arduino Mega
La carte est maintenant un **shield empilable** : les connecteurs Mega sont placés aux **positions
exactes de l'Arduino Mega 2560** (2 rangées à 48,26 mm, brochage déduit du cuivre d'origine, ordre
analogique A0→A15 vérifié), donc **le Mega s'enfiche dessous**. Layout : entrées (MIDI IN/OUT, jack,
DC) en haut, pots en grille 4×4 (filtres RC à côté de chaque pot), 4 boutons en colonne verticale,
LEDs à droite. **Le Mega est désormais SOUS les pots** (comme la carte d'origine) : les deux rangées
d'embases (pas 24 mm entre rangées de pots) s'intercalent dans les interstices entre rangées de pots,
y72 (analogique) et y120 (numérique). **100 % THT**, 4 couches + plan GND, **routé à 100 %, DRC
propre**, coins arrondis, **~172×172 mm** (carte resserrée, le Mega passe dessous). Empreintes des
embases/pots **sans courtyard** (carte empilée : les composants sont au-dessus du Mega, c'est normal).
4ᵉ sélection du mux = **D13** (D22 absent de ces 2 rangées). ⚠️ Dégager les pièces hautes du Mega
(USB, jack alim, condensateurs) — ne pas poser de composant pile au-dessus de ce coin.

**Connecteurs d'entrée (orientation finale, tous branchables par le bord HAUT) :**
- **MIDI DIN-5** (J1/J2) : empreinte custom `MIDI_DIN5_180deg` (géométrie reprise du PCB d'origine) — **trous de fixation en haut, arc des broches en dessous, broches data (4/5) les plus basses**, conforme à l'orientation du PCB d'origine.
- **Jack 6,35 mm** (J10) : Neutrik **NRJ6HF-1** horizontal, nez vers le bord haut (câble branché par le haut).
- **Jack DC barrel** (J3) : `BarrelJack_Horizontal` tourné de 270° → **ouverture vers le bord haut** (comme les autres entrées).
- **OLED** (J5) : header 1×4 simple, **sans sérigraphie de nom de broches**.
- Le mux **4067** et le filtre du jack sont placés dans l'**espace libre entre les deux rangées de headers Mega** (sinon la rangée analogique trop dense provoquait des courts A15/D10 à l'autoroutage).

---

## 1. Identification du projet

| | |
|---|---|
| **Projet** | MIDI SysEx Patcher Ver.2 |
| **Auteur** | baritonomarchetto (« Barito »), synthbrigade.altervista.org |
| **Version carte** | **v0.2b** (lue sur la sérigraphie, en bas à droite) |
| **Type** | Shield (carte fille) pour **Arduino MEGA 2560** |
| **Nature** | PCB **double face**, env. **135 × 120 mm** (trous de fixation aux coins : 129,5 × 115,6 mm) |
| **CAO d'origine** | EAGLE 6.6.0 (Gerbers générés le 28/01/2022) |
| **Instructable** | https://www.instructables.com/MIDI-SysEx-Patcher-Ver2/ |
| **Dépôt GitHub** | https://github.com/baritonomarchetto/arduino-SysEx-Patcher (firmware + Gerbers, licence **MIT**) |
| **Prototype d'origine** | « (almost) Universal MIDI SysEx CC Programmer » (même auteur, version perfboard sans écran) |

> ⚠️ Le `.GML` fourni n'est **pas** le contour complet de la carte (il ne couvre qu'une sous-zone),
> d'où le rognage si on l'utilise comme outline. Le contour réel est donné par les trous d'angle du perçage.

---

## 2. Nomenclature (BOM) — source : Instructable Ver.2

| Qté | Composant | Empreinte KiCad suggérée | Rôle |
|---|---|---|---|
| 1 | Arduino MEGA 2560 (embase) | headers shield MEGA (2×18, 2×8, 1×6, 1×8) | cerveau |
| 1 | **6N138** optocoupleur | DIP-8 (socket) | entrée MIDI isolée |
| 1 | OLED **SSD1306 0,96"** 128×64 I²C | header 1×4 (2,54 mm) | affichage |
| 16 | Potentiomètre **10 kΩ lin.**, montage PCB | Potentiometer_Alps_RK09K_Single (ou équiv. 3 pins + 2 brackets) | réglages |
| 3 | Résistance **220 Ω** | R_Axial THT (ou 0207) | 1× MIDI IN, 2× MIDI OUT |
| 1 | Résistance **330 Ω** | R_Axial THT | section 6N138 |
| 4 | Résistance **1 kΩ** | R_Axial THT | limitation des 4 LEDs |
| 1 | Résistance **10 kΩ** | R_Axial THT | pull-up sortie 6N138 |
| 1 | Condensateur **100 nF** (non pol.) | C_Disc THT | découplage |
| 1 | Condensateur **100 µF** électrolytique **polarisé** (C19) | CP_Radial D6,3 mm | réservoir/lissage sur le rail **+5 V** (pad 1 = **+** → +5V, pad 2 = − → GND ; polarité sérigraphiée) |
| 1 | Diode **1N4148** | D_DO-35 | protection entrée optocoupleur |
| 1 | Diode **1N4004** | D_DO-41 | protection inversion alim |
| 4 | **LED 3 mm** | LED_D3.0mm | retour visuel (pages / séquenceur) |
| 4 | Bouton poussoir momentané | SW_PUSH 6 mm | PAGE/SHIFT, CALLBACK/START, RNDMZ!/PANIC, MODE |
| ~~1~~ | ~~Inverseur SPDT PCB (SW1)~~ | ~~SW_SPDT~~ | **supprimé** — 6N138 câblé en direct sur RX0 (voir §3.5) |
| 1 | Jack DC barrel | BarrelJack | alimentation +5 V |
| 2 | Connecteur **MIDI DIN-5** | DIN-5 180° | MIDI IN / MIDI OUT |
| — | Bornier 4 pts | GND / +5V / −BAT / +BAT | alim alternative (pile 9 V) |
| 50 | Pin headers mâles 2,54 | — | embases shield |

---

## 3. Câblage numérique — source : firmware `CCSysEx_Patcher.ino`

### 3.1 Potentiomètres (16) → entrées analogiques du MEGA
Chaque potentiomètre : **broche 1 → GND**, **curseur (broche 2) → A_x**, **broche 3 → +5 V**.
Ordre de la matrice 4×4 (numérotation sérigraphie) → broche analogique (`potLayout`) :

| Pos. (silk) | Label shift | A-pin | | Pos. | Label shift | A-pin |
|---|---|---|---|---|---|---|
| **1** | BPM | **A0** | | **9** | — | **A2** |
| **2** | STEP LENGHT | **A5** | | **10** | — | **A6** |
| **3** | CH1 | **A8** | | **11** | — | **A10** |
| **4** | CH2 | **A12** | | **12** | — | **A14** |
| **5** | OCTAVE | **A1** | | **13** | — | **A3** |
| **6** | SYNTH | **A4** | | **14** | — | **A7** |
| **7** | — | **A9** | | **15** | — | **A11** |
| **8** | — | **A13** | | **16** | — | **A15** |

> `const int potLayout[16] = {A0,A5,A8,A12, A1,A4,A9,A13, A2,A6,A10,A14, A3,A7,A11,A15};`

### 3.2 Boutons (4) → broches numériques (mode `INPUT_PULLUP`)
Un côté du bouton → broche MEGA, l'autre côté → **GND** (pas de résistance externe, pull-up interne).

| Bouton (silk) | Broche |
|---|---|
| 4 boutons (PAGE/SHIFT, CALLBACK/START, RNDMZ!/PANIC, MODE) | **D7, D8, D6, D5** |

> `const byte butLayout[4] = {7, 8, 6, 5};`

### 3.3 LEDs (4) → broches numériques (sortie)
Broche MEGA → **1 kΩ** → anode LED → cathode → **GND**.

| LED | Broche |
|---|---|
| 4 LEDs (1 LED par groupe de 4 pots) | **D12, D11, D10, D9** |

> `const byte LEDLayout[4] = {12, 11, 10, 9};`

### 3.4 Écran OLED SSD1306 → **I²C**
| Signal | Broche MEGA |
|---|---|
| SDA | **D20 (SDA)** |
| SCL | **D21 (SCL)** |
| VCC | +5 V |
| GND | GND |

> Adresse I²C **0x3C**, 128×64. Header 1×4 « SSD1306 » en haut au centre de la carte.
> Vérifier l'ordre des broches du header (silk : SDA … GND) par rapport à votre module.

### 3.5 MIDI → **Serial0 matériel** (USB partagé)
Le firmware utilise le port **Serial** = **RX0 (D0)** / **TX0 (D1)** (`Serial.begin(31250)`).
À l'origine un inverseur **SW1 « prog/MIDI »** déconnectait la sortie du 6N138 de RX0 pendant l'upload
USB. **Supprimé dans cette refonte** : la sortie du 6N138 (Vo, collecteur ouvert + pull-up 10 kΩ R5)
est désormais **câblée directement à RX0 (D0)**. Conséquence pratique : ne pas téléverser le firmware
pendant qu'un flux MIDI entre (au repos le pull-up n'empêche pas l'upload USB).

---

## 4. Section analogique — **CONFIRMÉE par traçage du cuivre**

Le brochage et les liaisons ci-dessous ont été **vérifiés par extraction de la connectivité cuivre**
des Gerbers (rastérisation des couches + composantes connexes + liaison via les trous métallisés),
recoupée avec la sérigraphie du dessous (`board_bottom.png`) et le BOM.

**Orientation du 6N138 (U1) établie sans ambiguïté** : les deux pastilles électriquement isolées
tombent sur les broches **NC (1 et 4)**, la pastille du rail +5V (partagé avec les 16 pots) sur **Vcc (8)**,
et la pastille du plan de masse sur **GND (5)**.

### 4.1 MIDI IN (optocoupleur 6N138) — tracé vérifié
```
DIN-5 (IN) br.4 ──[R1 220Ω]── 6N138 pin2 (Anode LED)        ✓ tracé
DIN-5 (IN) br.5 ───────────── 6N138 pin3 (Cathode)          ✓ tracé
                 D1 1N4148 entre pin2 (Anode) et pin3 (Cathode), protection  ✓ tracé
6N138 pin8 (Vcc) ── +5V        6N138 pin5 ── GND            ✓ tracé
6N138 pin6 (Vo)  ──[R5 10kΩ]── +5V   (pull-up)              ✓ tracé
6N138 pin6 (Vo)  ──────────────────────────── RX0 (D0)      (direct, SW1 supprimé)
6N138 pin7 (Vb)  ──[R4 330Ω]── GND   (polarisation base)    ✓ tracé
6N138 pin1, pin4 = NC                                       ✓ (pastilles isolées)
C1 100nF : découplage +5V/GND
```
> Tous les pads correspondants ont été localisés (coords mm dans l'analyse). Ce câblage = circuit
> MIDI IN 6N138 standard, ici intégralement confirmé sur le cuivre — pas une simple hypothèse.

### 4.2 MIDI OUT
```
TX0 (D1) ──[220Ω]── DIN-5 (OUT) br.5
+5V      ──[220Ω]── DIN-5 (OUT) br.4
DIN-5 (OUT) br.2 ── GND (blindage)
```

### 4.3 Alimentation
```
Barrel +5V (centre +) ──[1N4004 protection]── rail +5V
Bornier : GND / +5V / −BAT / +BAT (alternatives d'alim)
(SW1 « prog/MIDI » supprimé — 6N138 Vo câblé en direct sur RX0)
```

> Les 3×220 Ω, 330 Ω, 10 kΩ, 100 nF, 1N4148, 1N4004 sont **tous** présents et localisés ;
> seuls quelques nœuds exacts autour du 6N138 (pin7, rôle du 330 Ω) restent à confirmer en
> suivant les pistes sur `board_top.svg` / `board_bottom.svg` (zoomables).

---

## 5. Démarche conseillée sous KiCad

1. **Nouveau projet** KiCad → schéma.
2. Placer un symbole **Arduino MEGA 2560** (lib `MCU_Module:Arduino_Mega2560_Shield` existe dans KiCad).
3. Câbler les **16 pots**, **4 boutons**, **4 LEDs+1kΩ**, **OLED 1×4** selon les tables §3.
4. Ajouter la **section MIDI** (6N138 + 2 DIN-5) et l'**alim** selon §4 (circuit MIDI standard).
5. Associer les **empreintes** (§2). Pour le PCB, vous pouvez :
   - **partir des Gerbers** (les `board_*.svg` donnent l'implantation exacte à reproduire), ou
   - importer les Gerbers dans **GerbView → Exporter vers Pcbnew** comme calque de référence graphique.
6. Vérifier les nœuds analogiques douteux en zoomant `board_top.svg`/`board_bottom.svg`.

> Le plus simple si le but est juste de **refabriquer** la carte telle quelle : les Gerbers d'origine
> suffisent (à renvoyer chez JLCPCB). La reconstruction du schéma n'est nécessaire que pour **modifier**
> le circuit.

---

## 6. Fichiers de ce dossier

| Fichier | Contenu |
|---|---|
| `board_top.svg` / `board_top.png` | Rendu **dessus** (cuivre + sérigraphie + pads + perçage), vectoriel zoomable |
| `board_bottom.svg` / `board_bottom.png` | Rendu **dessous** (vue mirroir, section analogique/alim) |
| `firmware_CCSysEx_Patcher.ino` | Firmware officiel (source du câblage numérique) — licence MIT |
| `firmware_LICENSE.txt` | Licence MIT du firmware |
| `RECONSTRUCTION_SCHEMA.md` | Ce document |
| `kicad_project/SysEx_Patcher.kicad_pro` | **Projet KiCad 10** (à ouvrir dans KiCad) |
| `kicad_project/SysEx_Patcher.kicad_sch` | **Schéma reconstruit** : 46 composants, 150 connexions, **ERC 0 erreur** |
| `kicad_project/SysEx_Patcher_schematic.pdf` | Export PDF du schéma |
| `kicad_project/SysEx_Patcher.kicad_pcb` | **PCB de départ** : 46 empreintes nettées, contour 135×120 mm |
| `kicad_project/pcb_top_preview.png` | Aperçu du PCB de départ |

### À propos du PCB de départ
- 46 empreintes placées avec **tous les nets assignés** (le chevelu/ratsnest s'affiche à l'ouverture) +
  **contour de carte Edge.Cuts ~135×118 mm** (taille réelle relevée sur le perçage).
- **Positions réelles d'après le perçage** : les 21 composants dominants — **16 potentiomètres (grille 4×4),
  6N138 (U1), 4 boutons** — sont placés à leur **emplacement physique réel** (registration par
  correspondance de constellations de trous, validée contre la sérigraphie). Le reste (résistances,
  diodes, DIN, OLED, SW1, headers MEGA) est en **zone de staging sous la carte**, à positionner
  (empreintes sans perçage standard / abstractions de shield). Voir `pcb_realpos_preview.png`.
- Rien n'est routé — état « prêt à placer/router », DRC = ratsnest + chevauchements de staging (pas de court-circuit).
- Le **DRC** ne remonte que : connexions manquantes (= ratsnest, normal avant routage), quelques
  chevauchements de placement à réorganiser, et des avertissements « lib non configurée » propres à la CLI.
- ~~Empreinte MIDI DIN = placeholder~~ → **résolu** : empreinte custom `MIDI_DIN5_180deg` (géométrie d'origine, orientation conforme au PCB d'origine). Voir §0bis.
- Les empreintes des connecteurs MEGA (J6/J7/J8) débordent à droite du contour : à repositionner
  comme headers d'empilage du shield.

### À propos du projet KiCad
- Schéma généré puis **validé par `kicad-cli` (ERC : 0 erreur)**. Les composants utilisent les
  symboles standard KiCad (Device:R, Isolator:6N138, Connector:DIN-5, Device:R_Potentiometer, …),
  embarqués dans le fichier — il s'ouvre donc sans dépendance.
- **Connectivité par labels globaux** portant les noms de broches Arduino (`A0`, `D7`, `+5V`, `RX0`…).
  Le MEGA est représenté par 3 embases (J6 analogique, J7 numérique, J8 alim) = les headers du shield.
- À l'ouverture, KiCad peut afficher des avertissements « librairie non trouvée » selon ta config :
  réassocie au besoin les symboles aux libs globales (clic droit → *Change Symbols*). Les empreintes
  sont des suggestions (§2) à confirmer avant routage.
- Les valeurs/refs suivent §2 et §4 ; les 16 pots = RV1…RV16, le 6N138 = U1 (Vo direct sur RX0, SW1 retiré).

*Rendus générés avec gerbonara depuis les Gerbers `SysEx_Programmer_BIG_display.*`.*

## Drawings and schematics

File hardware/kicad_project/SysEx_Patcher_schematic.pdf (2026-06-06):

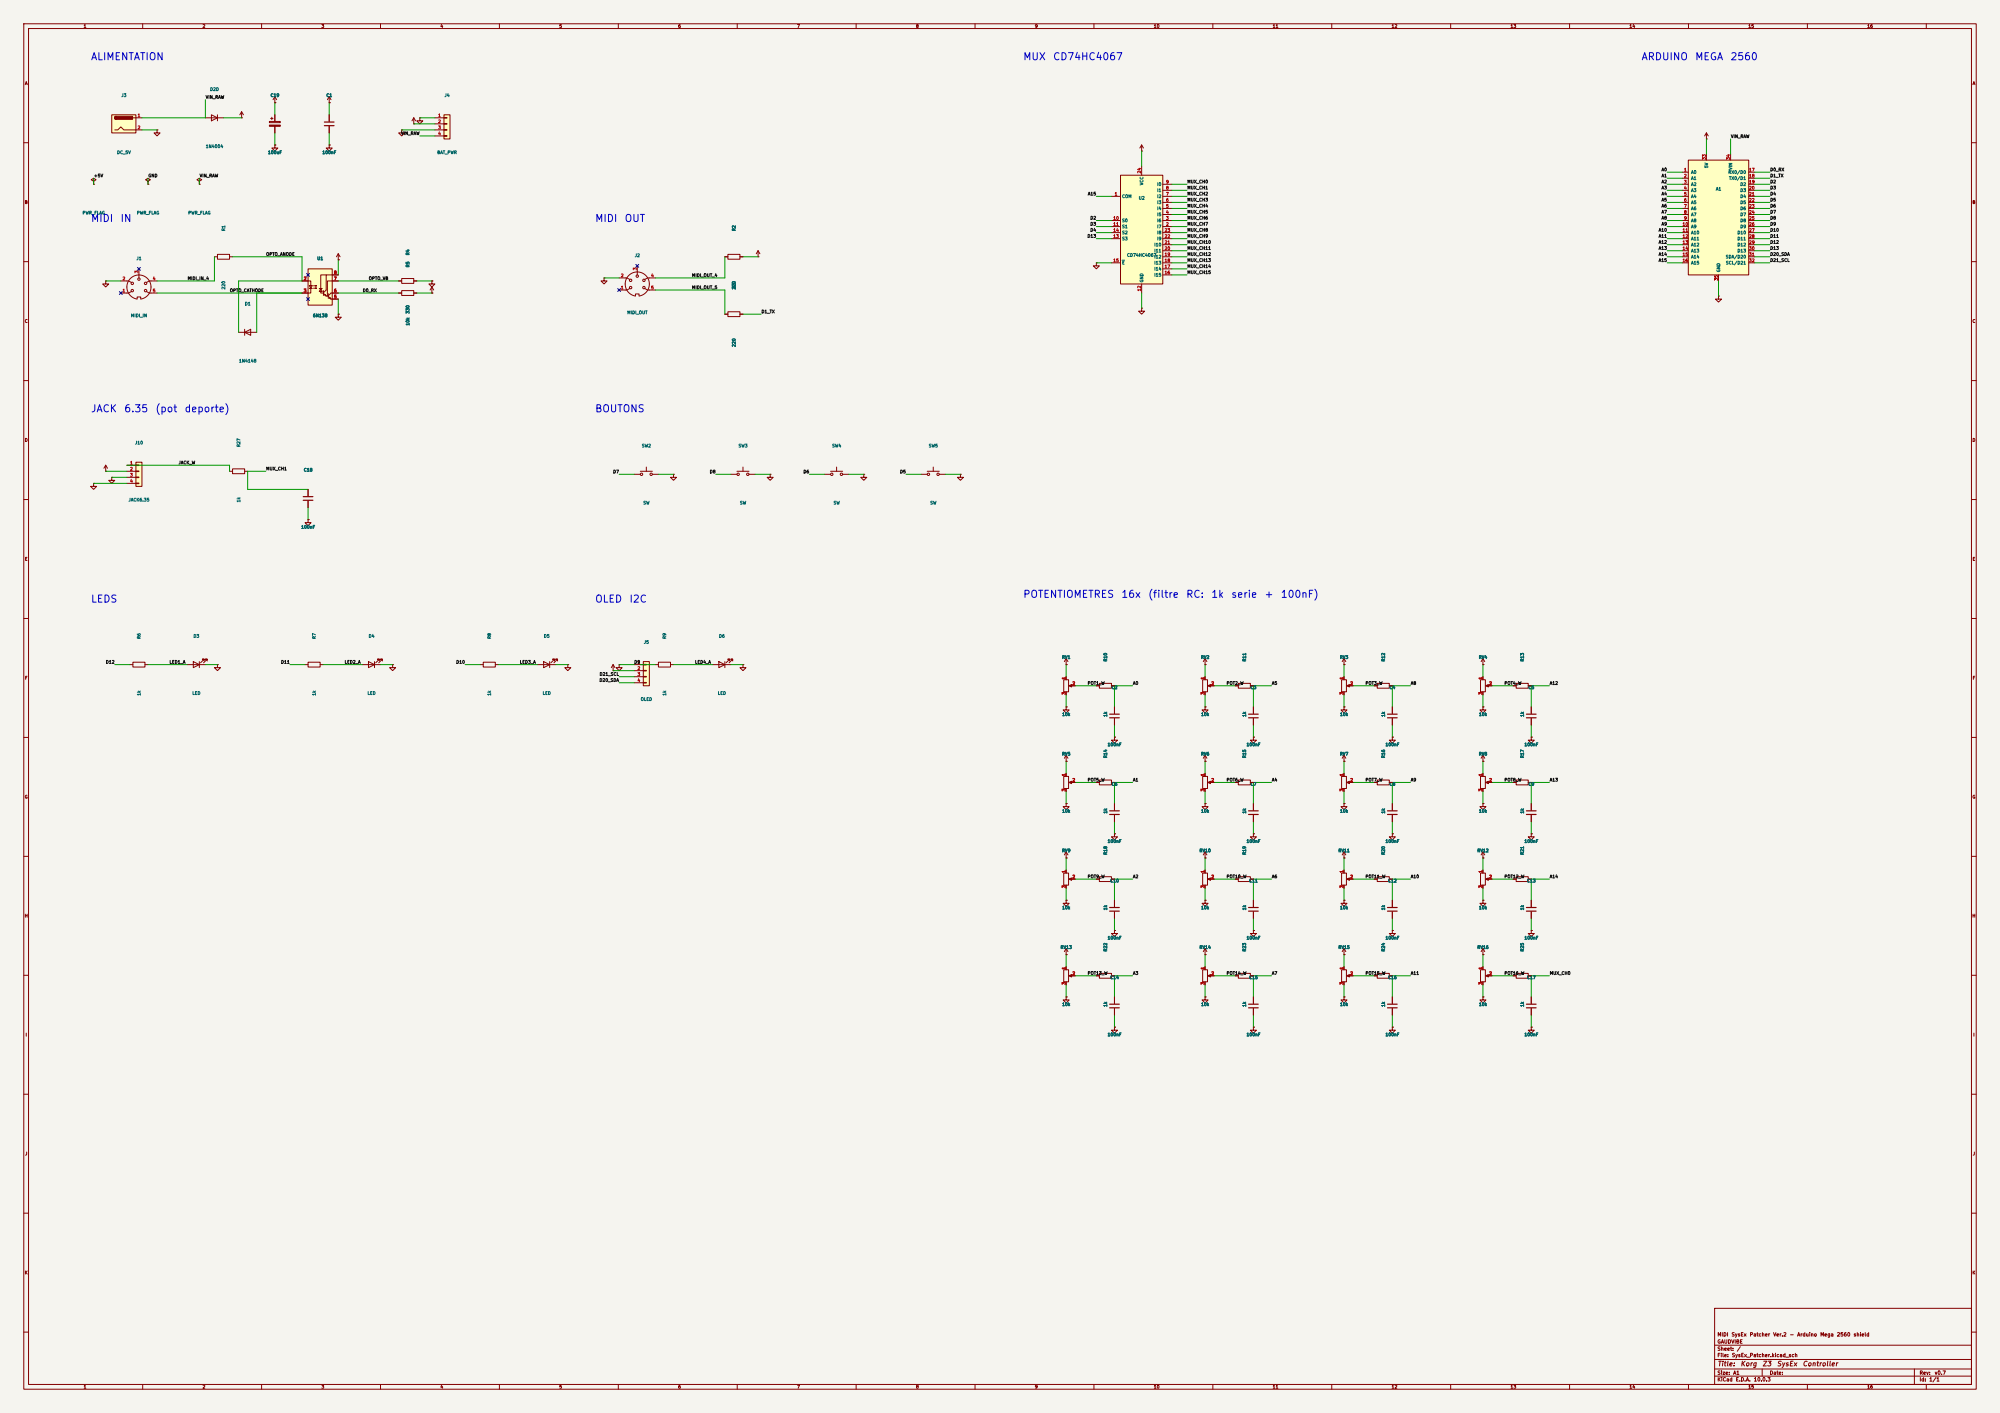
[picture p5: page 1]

POTENTIOMETRES 16x (filtre RC: 1k serie + 100nF) LEDS

MIDI SysEx Patcher Ver.2 - Arduino Mega 2560 shield
GAUDVIBE
Sheet: /
File: SysEx_Patcher.kicad_sch
Title: Korg Z3 SysEx Controller

Size: A1 | Rev: v0.7
KiCad E.D.A. 10.0.3 | Id: 1/1

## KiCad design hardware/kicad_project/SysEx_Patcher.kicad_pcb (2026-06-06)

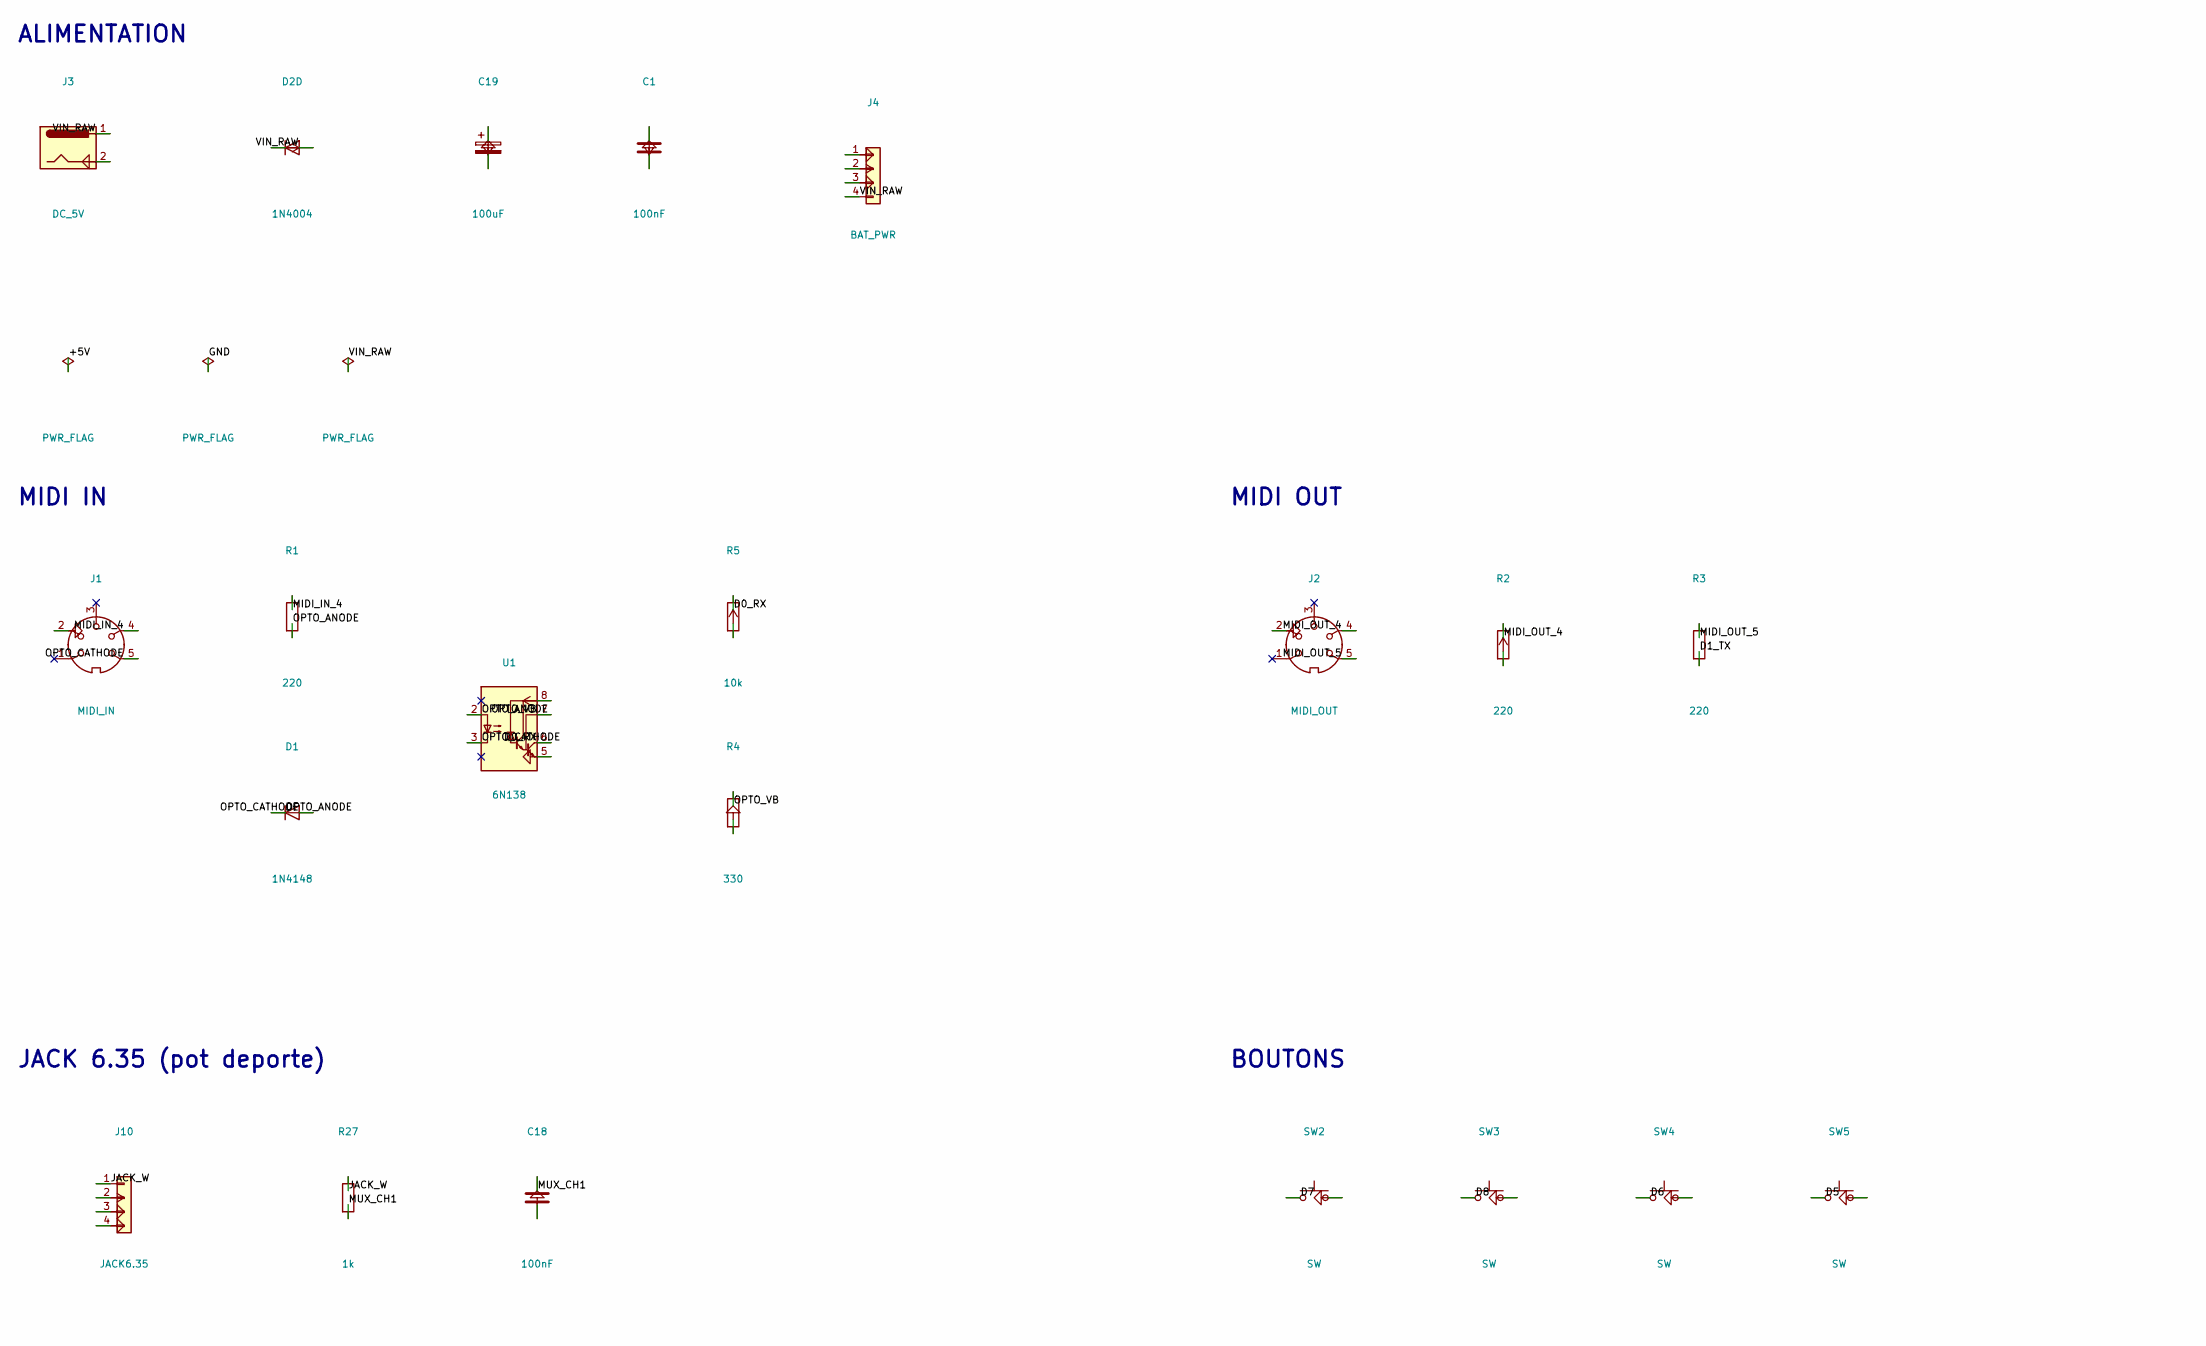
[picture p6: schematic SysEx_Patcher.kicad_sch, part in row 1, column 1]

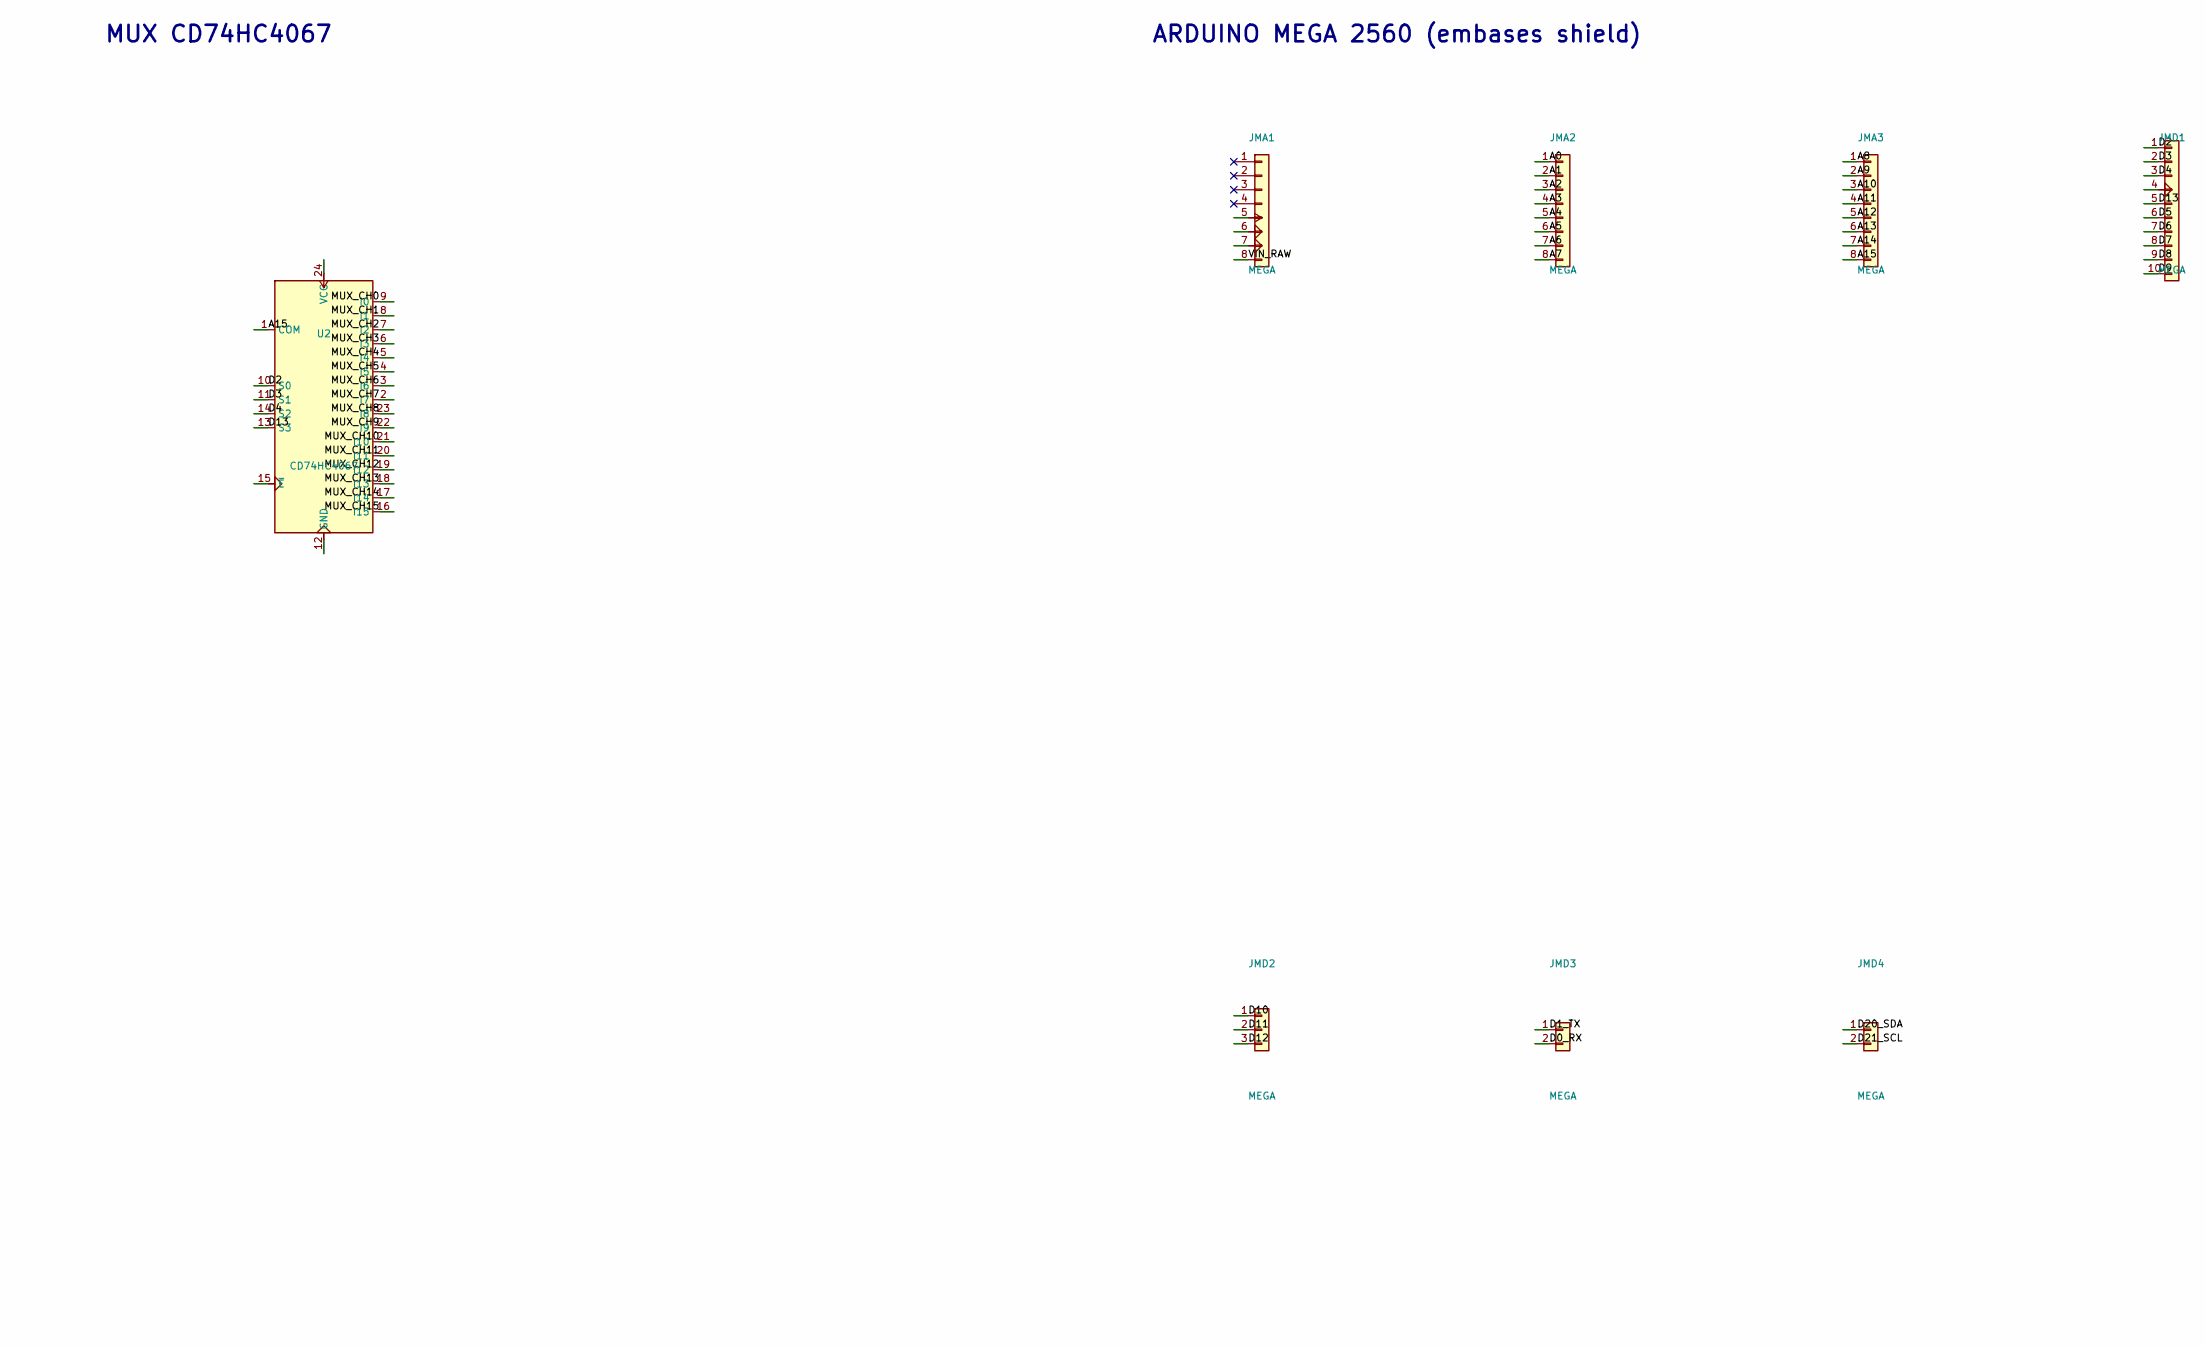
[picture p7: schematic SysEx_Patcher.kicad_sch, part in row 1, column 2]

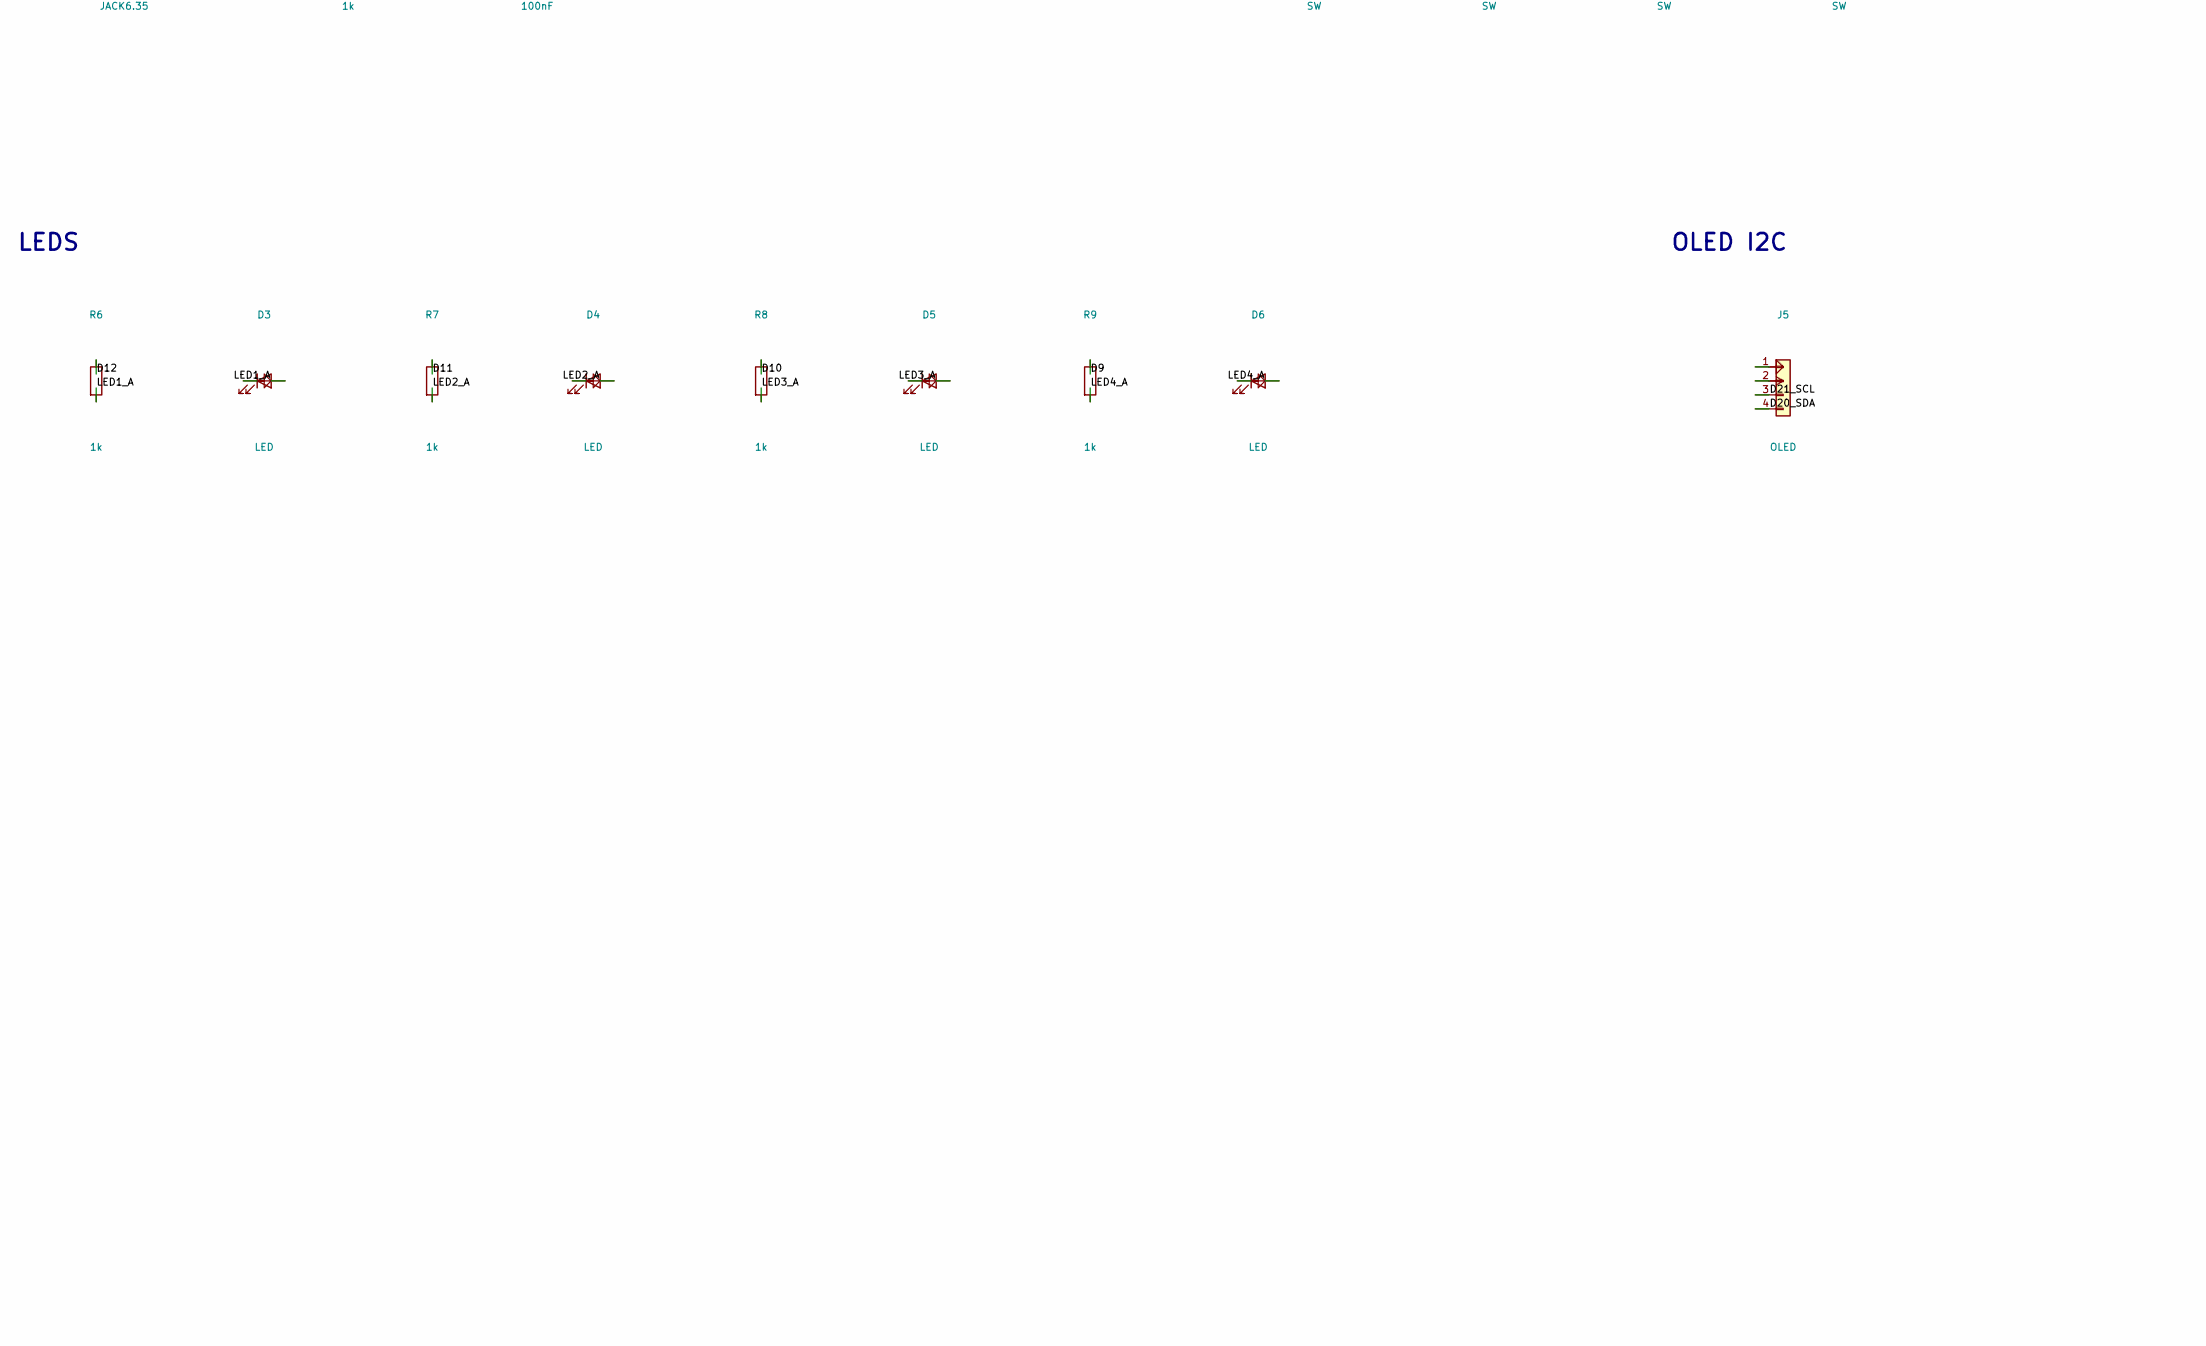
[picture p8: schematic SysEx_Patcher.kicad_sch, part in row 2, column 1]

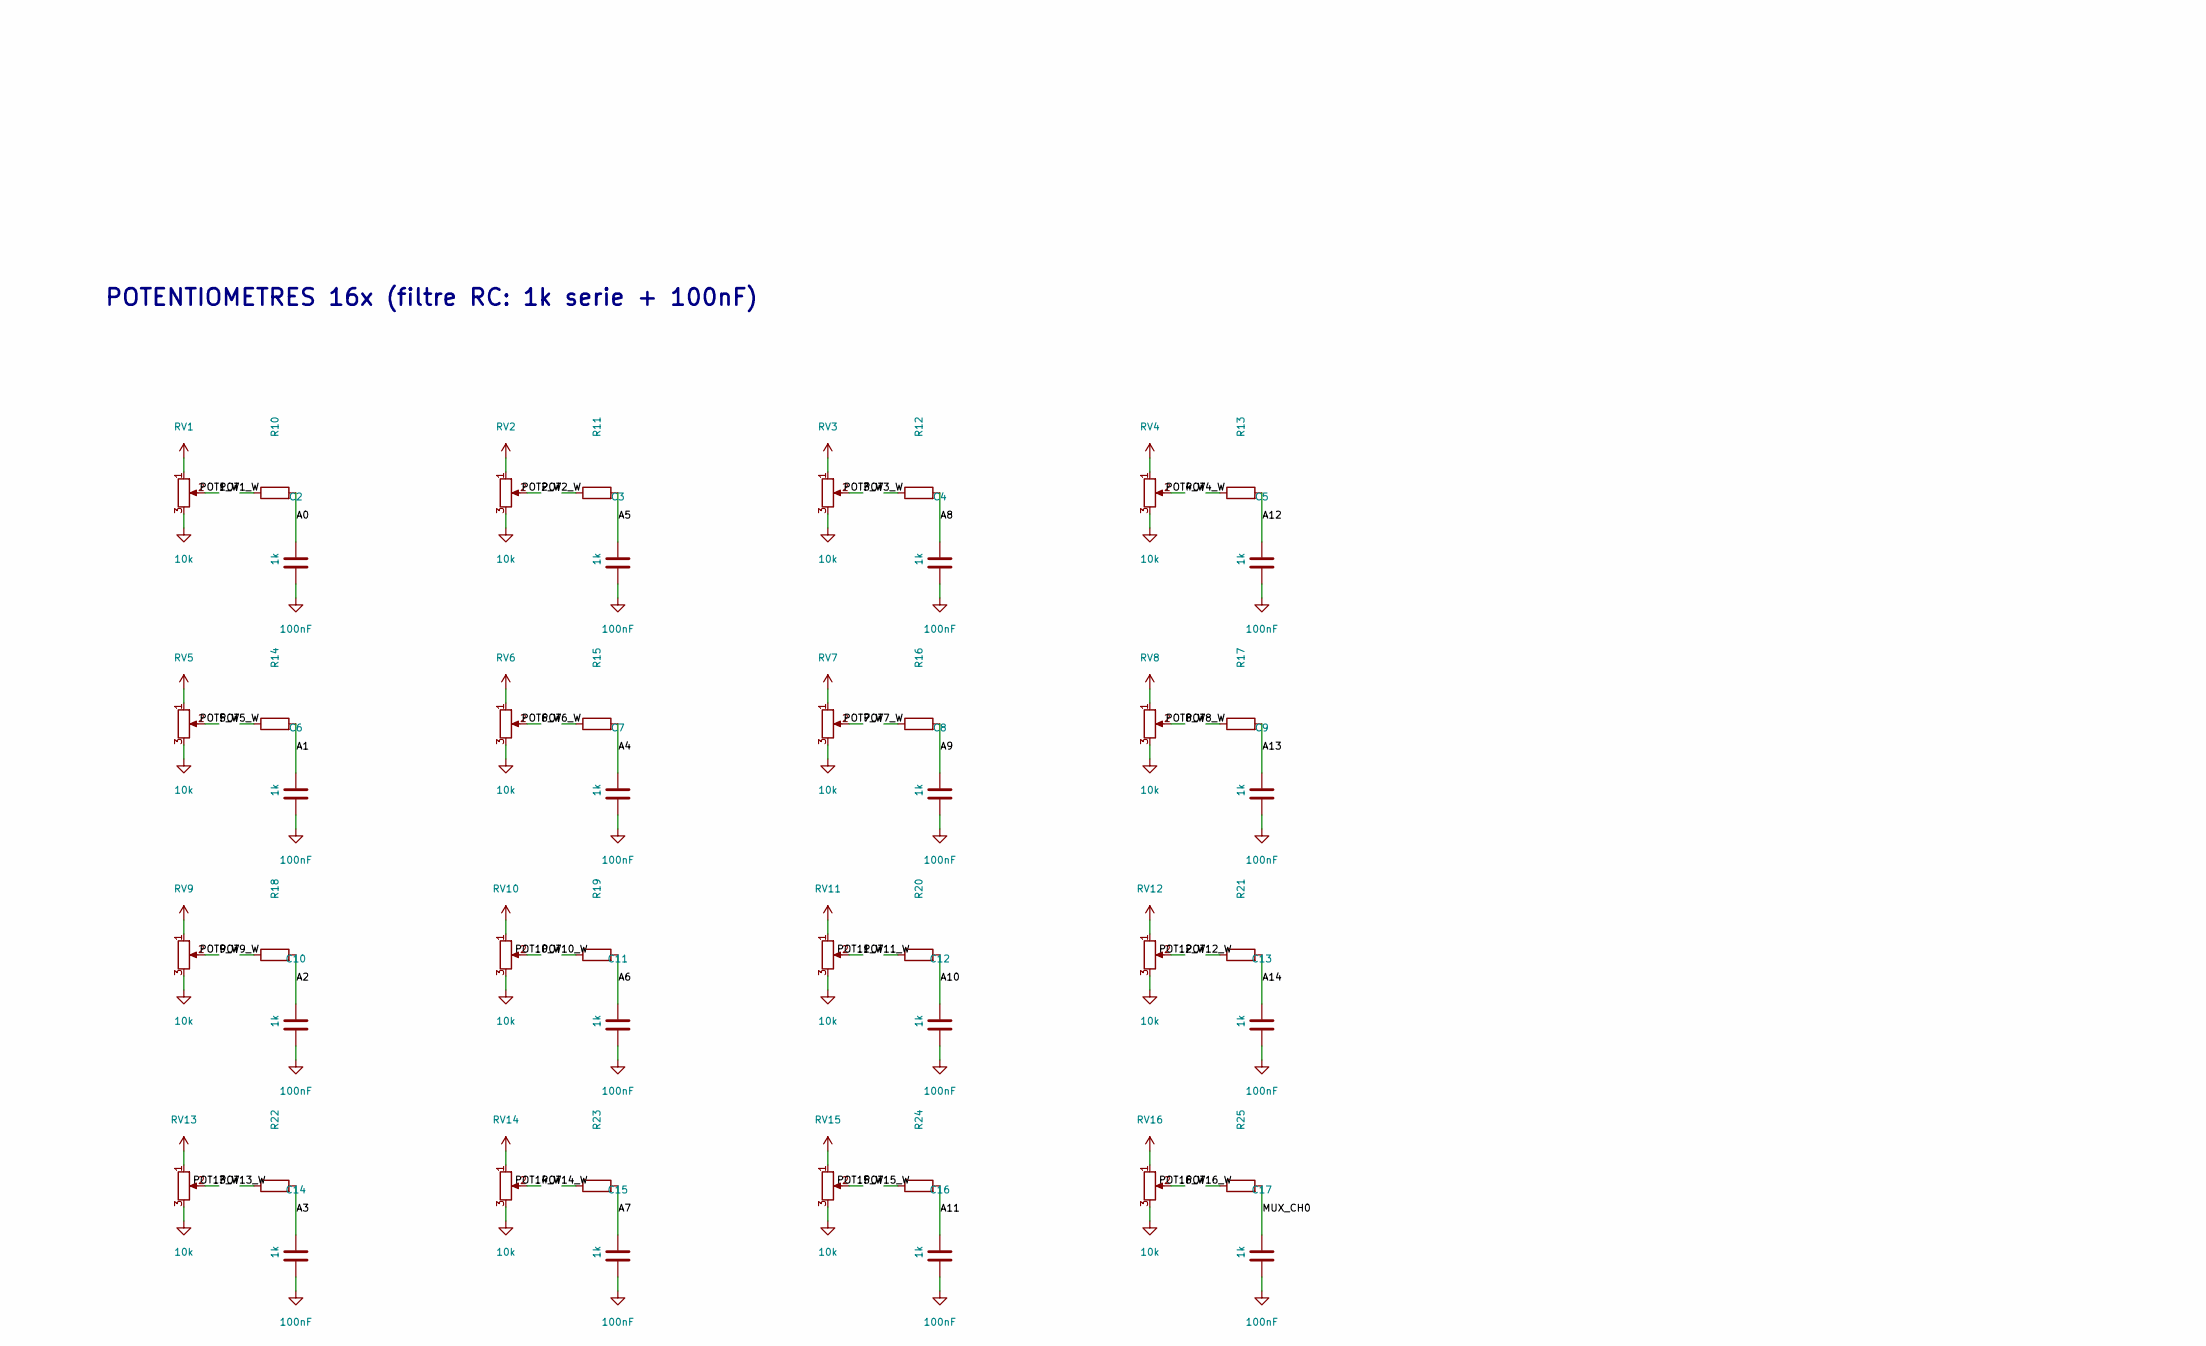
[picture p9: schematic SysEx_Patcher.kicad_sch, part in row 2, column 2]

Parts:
C1, C2, C3, C4, C5, C6, C7, C8, C9, C10, C11, C12, C13, C14, C15, C16, C17, C18: 100nF; C_Disc_D5.0mm_W2.5mm_P5.00mm
C19: 100uF; CP_Radial_D6.3mm_P2.50mm
D1: 1N4148; D_DO-35_SOD27_P7.62mm_Horizontal
D2D: 1N4004; D_DO-41_SOD81_P10.16mm_Horizontal
D3, D4, D5, D6: LED; LED_D3.0mm
J1: MIDI_IN; MIDI_DIN5_180deg
J2: MIDI_OUT; MIDI_DIN5_180deg
J3: DC_5V; BarrelJack_Horizontal
J4: BAT_PWR; PinHeader_1x04_P2.54mm_Vertical
J5: OLED; PinHeader_1x04_P2.54mm_Vertical
J10: JACK6.35; Jack_6.35mm_Neutrik_NRJ6HF-1_Horizontal
JMA1, JMA2, JMA3: MEGA; PinHeader_1x08_P2.54mm_Vertical
JMD1: MEGA; PinHeader_1x10_P2.54mm_Vertical
JMD2: MEGA; PinHeader_1x03_P2.54mm_Vertical
JMD3, JMD4: MEGA; PinHeader_1x02_P2.54mm_Vertical
R1, R2, R3: 220; R_Axial_DIN0207_L6.3mm_D2.5mm_P10.16mm_Horizontal
R4: 330; R_Axial_DIN0207_L6.3mm_D2.5mm_P10.16mm_Horizontal
R5: 10k; R_Axial_DIN0207_L6.3mm_D2.5mm_P10.16mm_Horizontal
R6, R7, R8, R9, R10, R11, R12, R13, R14, R15, R16, R17, R18, R19, R20, R21, R22, R23, R24, R25, R27: 1k; R_Axial_DIN0207_L6.3mm_D2.5mm_P10.16mm_Horizontal
RV1, RV2, RV3, RV4, RV5, RV6, RV7, RV8, RV9, RV10, RV11, RV12, RV13, RV14, RV15, RV16: 10k; Potentiometer_Alps_RK09K_Single_Vertical
SW2, SW3, SW4, SW5: SW; SW_PUSH_6mm
U1: 6N138; DIP-8_W7.62mm
U2: CD74HC4067; DIP-24_W15.24mm

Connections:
+5V: C1.1, C19.1, D2D.1 (K), J4.2, J5.2, J10.2, J10.R, JMA1.5, R2.2, R5.2, RV1.1, RV2.1, RV3.1, RV4.1, RV5.1, RV6.1, RV7.1, RV8.1, RV9.1, RV10.1, RV11.1, RV12.1, RV13.1, RV14.1, RV15.1, RV16.1, U1.8 (VCC), U2.24 (VCC)
A0: C2.1, JMA2.1, R10.2
A1: C6.1, JMA2.2, R14.2
A2: C10.1, JMA2.3, R18.2
A3: C14.1, JMA2.4, R22.2
A4: C7.1, JMA2.5, R15.2
A5: C3.1, JMA2.6, R11.2
A6: C11.1, JMA2.7, R19.2
A7: C15.1, JMA2.8, R23.2
A8: C4.1, JMA3.1, R12.2
A9: C8.1, JMA3.2, R16.2
A10: C12.1, JMA3.3, R20.2
A11: C16.1, JMA3.4, R24.2
A12: C5.1, JMA3.5, R13.2
A13: C9.1, JMA3.6, R17.2
A14: C13.1, JMA3.7, R21.2
A15: JMA3.8, U2.1 (COM)
D0_RX: JMD3.2, R5.1, U1.6 (VO2)
D1_TX: JMD3.1, R3.2
D2: JMD1.1, U2.10 (S0)
D3: JMD1.2, U2.11 (S1)
D4: JMD1.3, U2.14 (S2)
D5: JMD1.6, SW5.1
D6: JMD1.7, SW4.1
D7: JMD1.8, SW2.1
D8: JMD1.9, SW3.1
D9: JMD1.10, R9.1
D10: JMD2.1, R8.1
D11: JMD2.2, R7.1
D12: JMD2.3, R6.1
D13: JMD1.5, U2.13 (S3)
D20_SDA: J5.4, JMD4.1
D21_SCL: J5.3, JMD4.2
GND: C1.2, C2.2, C3.2, C4.2, C5.2, C6.2, C7.2, C8.2, C9.2, C10.2, C11.2, C12.2, C13.2, C14.2, C15.2, C16.2, C17.2, C18.2, C19.2, D3.1 (K), D4.1 (K), D5.1 (K), D6.1 (K), J1.2, J2.2, J3.2, J4.1, J4.3, J5.1, J10.3, J10.4, J10.G, J10.S, JMA1.6, JMA1.7, JMD1.4, R4.2, RV1.3, RV2.3, RV3.3, RV4.3, RV5.3, RV6.3, RV7.3, RV8.3, RV9.3, RV10.3, RV11.3, RV12.3, RV13.3, RV14.3, RV15.3, RV16.3, SW2.2, SW3.2, SW4.2, SW5.2, U1.5 (GND), U2.12 (GND), U2.15 (~E)
JACK_W: J10.1, J10.T, R27.1
LED1_A: D3.2 (A), R6.2
LED2_A: D4.2 (A), R7.2
LED3_A: D5.2 (A), R8.2
LED4_A: D6.2 (A), R9.2
MIDI_IN_4: J1.4, R1.1
MIDI_OUT_4: J2.4, R2.1
MIDI_OUT_5: J2.5, R3.1
MUX_CH0: C17.1, R25.2, U2.9 (I0)
MUX_CH1: C18.1, R27.2, U2.8 (I1)
MUX_CH2: U2.7 (I2)
MUX_CH3: U2.6 (I3)
MUX_CH4: U2.5 (I4)
MUX_CH5: U2.4 (I5)
MUX_CH6: U2.3 (I6)
MUX_CH7: U2.2 (I7)
MUX_CH8: U2.23 (I8)
MUX_CH9: U2.22 (I9)
MUX_CH10: U2.21 (I10)
MUX_CH11: U2.20 (I11)
MUX_CH12: U2.19 (I12)
MUX_CH13: U2.18 (I13)
MUX_CH14: U2.17 (I14)
MUX_CH15: U2.16 (I15)
OPTO_ANODE: D1.1 (K), R1.2, U1.2 (C1)
OPTO_CATHODE: D1.2 (A), J1.5, U1.3 (C2)
OPTO_VB: R4.1, U1.7 (VO1)
POT1_W: R10.1, RV1.2
POT2_W: R11.1, RV2.2
POT3_W: R12.1, RV3.2
POT4_W: R13.1, RV4.2
POT5_W: R14.1, RV5.2
POT6_W: R15.1, RV6.2
POT7_W: R16.1, RV7.2
POT8_W: R17.1, RV8.2
POT9_W: R18.1, RV9.2
POT10_W: R19.1, RV10.2
POT11_W: R20.1, RV11.2
POT12_W: R21.1, RV12.2
POT13_W: R22.1, RV13.2
POT14_W: R23.1, RV14.2
POT15_W: R24.1, RV15.2
POT16_W: R25.1, RV16.2
VIN_RAW: D2D.2 (A), J3.1, J4.4, JMA1.8

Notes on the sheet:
ALIMENTATION
MIDI IN
MIDI OUT
JACK 6.35 (pot deporte)
BOUTONS
LEDS
OLED I2C
MUX CD74HC4067
ARDUINO MEGA 2560 (embases shield)
POTENTIOMETRES 16x (filtre RC: 1k serie + 100nF)

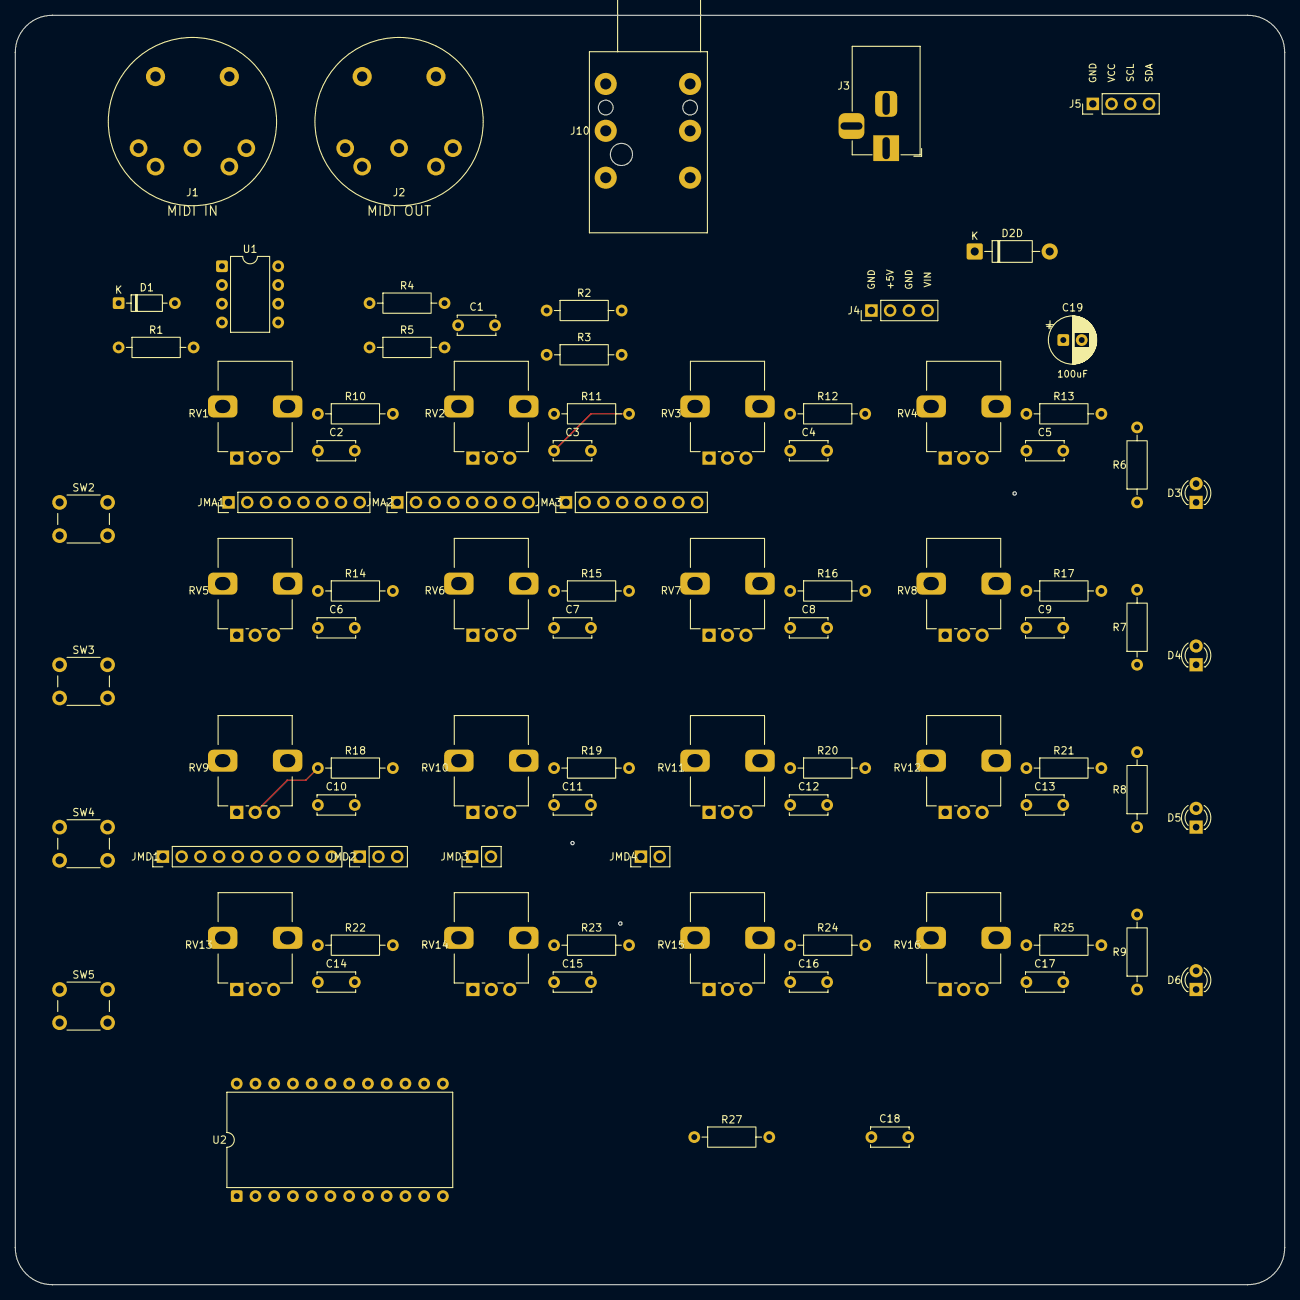
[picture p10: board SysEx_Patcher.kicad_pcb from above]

Board: 4 copper layers, 172.0 x 172.0 mm, 86 parts (0 on the bottom side), 64 nets.

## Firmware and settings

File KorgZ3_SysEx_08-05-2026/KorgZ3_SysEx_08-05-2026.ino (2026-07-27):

/**
 * KORG Z3 - Contrôleur 16 potentiomètres, 5 pages, OLED
 * Version avec Dump Request dynamique + persistance EEPROM
 *
 * Boutons :
 *  - Pin 7 (−)  : page précédente
 *  - Pin 8 (+)  : page suivante
 *  - Pin 5      : appui court → naviguer dans les dumps mémorisés
 *                 appui long ≥3s → sauvegarder le dump en cours (RAM + EEPROM)
 *  - Pin 6      : appui long ≥3s → envoyer Dump Request au Z3 et recevoir le dump
 *
 * LEDs de page : pin 12=I, pin 11=II, pin 10=III (pages IV et V sans LED)
 * LED confirmation sauvegarde : pin 9
 *
 * EEPROM layout (Arduino Mega = 4096 octets) :
 *  @0       : magic byte 0xA5
 *  @1       : presetCount
 *  @2       : currentSlot
 *  @3 + n*108 : slots (2 size + 10 name + 96 data = 108 octets/slot)
 *  Total : 3 + 8×108 = 867 octets sur 4096 disponibles.
 *
 * Bibliothèques : Wire.h, Adafruit_GFX.h, Adafruit_SSD1306.h, EEPROM.h
 */

#include <Wire.h>
#include <Adafruit_GFX.h>
#include <Adafruit_SSD1306.h>
#include <EEPROM.h>

// =================== ÉCRAN OLED ===================
#define SCREEN_WIDTH 128
#define SCREEN_HEIGHT 32
#define OLED_RESET    -1
Adafruit_SSD1306 display(SCREEN_WIDTH, SCREEN_HEIGHT, &Wire, OLED_RESET);

// =================== PRESETS ===================
const int DUMP_MAX_SIZE = 96;
const int MAX_PRESETS   = 8;

struct DumpSlot {
  byte data[DUMP_MAX_SIZE];
  int  size;
  char name[10];
  bool valid;
};

DumpSlot presetSlots[MAX_PRESETS];
int      presetCount = 0;
int      currentSlot = 0;

byte sendBuffer[DUMP_MAX_SIZE];
int  sendBufferSize = 0;
char currentName[10] = "--------";

// =================== PRESETS USINE ===================
// Places en PROGMEM : sur AVR un `const byte[]` ordinaire occupe la RAM,
// dont il ne reste qu'environ 3 Ko. La flash, elle, est utilisee a 10 %.

// Preset 0 — SynLead, cree a partir du DynoPian d'usine.
// Le nom embarque disait encore «DynoPian» : corrige, car c'est lui que le
// Z3 affiche et dont extractName() derive le nom montre sur l'ecran.
const byte SYNLEAD_DUMP[] PROGMEM = {
  0xF0, 0x42, 0x30, 0x1D, 0x40,          // en-tete SysEx
  0x53, 0x79, 0x6E, 0x4C, 0x65, 0x61, 0x64, 0x20,   // nom, 8 caracteres
  0x03, 0x02, 0x02, 0x01, 0x2F, 0x17, 0x03, 0x04, 0x02, 0x02,
  0x01, 0x00, 0x01, 0x0A, 0x01, 0x01, 0x01, 0x00, 0x00, 0x00,
  0x00, 0x03, 0x07, 0x07, 0x03, 0x00, 0x00, 0x00, 0x00, 0x63,
  0x1C, 0x62, 0x00, 0x19, 0x18, 0x06, 0x15, 0x00, 0x00, 0x00,
  0x1F, 0x00, 0x02, 0x00, 0x00, 0x00, 0x1F, 0x00, 0x06, 0x0E,
  0x08, 0x07, 0x08, 0x01, 0x00, 0x00, 0x00, 0x00, 0x00, 0x01,
  0x00, 0x02, 0x01, 0x00, 0x00, 0x00, 0x00, 0x00, 0x00, 0x00,
  0x00, 0x00, 0x00, 0x04, 0x06, 0x02, 0x04, 0x00, 0x00, 0x03,
  0x00,
  0xF7
};

// Preset 1 — FlutAtk : la flute douce du Z3, rendue sensible a l'attaque.
// Le Flute__1 d'origine n'avait de Velocity Int que sur C-2, une PORTEUSE :
// la velocite n'y faisait varier que le VOLUME, jamais le timbre. On l'ajoute
// sur les MODULATEURS M-1 et M-2 (valeur 8), ce qui ouvre le timbre quand on
// attaque fort — le comportement de SynLead, transpose sur un son doux.
// Six octets seulement different du dump d'origine : le nom, et ces deux la.
// Dosable en direct sur la page V, potentiometres M1Velo (A0) et M2Velo (A8).
const byte FLUTE_ATK_DUMP[] PROGMEM = {
  0xF0, 0x42, 0x30, 0x1D, 0x40,          // en-tete SysEx
  0x46, 0x6C, 0x75, 0x74, 0x41, 0x74, 0x6B, 0x20,   // nom, 8 caracteres
  0x03, 0x07, 0x02, 0x01, 0x4B, 0x20, 0x04, 0x26, 0x00, 0x00,
  0x00, 0x00, 0x00, 0x03, 0x04, 0x02, 0x02, 0x00, 0x00, 0x00,
  0x00, 0x04, 0x04, 0x04, 0x04, 0x01, 0x00, 0x00, 0x00, 0x1B,
  0x2F, 0x24, 0x46, 0x1F, 0x1F, 0x1F, 0x10, 0x14, 0x11, 0x1F,
  0x1F, 0x05, 0x02, 0x00, 0x00, 0x13, 0x00, 0x00, 0x00, 0x09,
  0x06, 0x05, 0x0B, 0x01, 0x00, 0x00, 0x01, 0x00, 0x00, 0x00,
  0x01, 0x00, 0x00, 0x00, 0x00, 0x00, 0x00, 0x00, 0x00, 0x00,
  0x00, 0x00, 0x00, 0x08, 0x00, 0x08, 0x0A, 0x00, 0x04, 0x04,
  0x01,
  0xF7
};

struct FactoryPreset { const byte* data; byte size; };
const FactoryPreset FACTORY[] = {
  { SYNLEAD_DUMP,   sizeof(SYNLEAD_DUMP)   },
  { FLUTE_ATK_DUMP, sizeof(FLUTE_ATK_DUMP) }
};
const int FACTORY_COUNT = sizeof(FACTORY) / sizeof(FACTORY[0]);

// =================== EEPROM ===================
const byte EE_MAGIC        = 0xA5;
const int  EE_ADDR_MAGIC   = 0;
const int  EE_ADDR_COUNT   = 1;
const int  EE_ADDR_CURRENT = 2;
const int  EE_ADDR_SLOTS   = 3;
const int  SLOT_EE_SIZE    = 108;
// Nombre de presets usine deja installes sur cet appareil. Place bien APRES la
// zone des slots (3 + 8 x 108 = 867) pour ne pas invalider les enregistrements
// existants lors de la mise a jour du firmware. 0xFF = jamais ecrit.
const int  EE_ADDR_FACTORY = 900;

int slotEEAddr(int n) { return EE_ADDR_SLOTS + n * SLOT_EE_SIZE; }

void eeWriteByte(int addr, byte val) {
  if (EEPROM.read(addr) != val) EEPROM.write(addr, val);
}

void eeWriteSlot(int idx) {
  if (idx < 0 || idx >= MAX_PRESETS) return;
  int base = slotEEAddr(idx);
  eeWriteByte(base,     (byte)(presetSlots[idx].size & 0xFF));
  eeWriteByte(base + 1, (byte)((presetSlots[idx].size >> 8) & 0xFF));
  for (int i = 0; i < 10; i++)
    eeWriteByte(base + 2 + i, (byte)presetSlots[idx].name[i]);
  for (int i = 0; i < DUMP_MAX_SIZE; i++)
    eeWriteByte(base + 12 + i, presetSlots[idx].data[i]);
}

void eeReadSlot(int idx) {
  if (idx < 0 || idx >= MAX_PRESETS) return;
  int base = slotEEAddr(idx);
  int sz = (int)EEPROM.read(base) | ((int)EEPROM.read(base + 1) << 8);
  if (sz < 6 || sz > DUMP_MAX_SIZE) {
    presetSlots[idx].valid = false;
    presetSlots[idx].size  = 0;
    return;
  }
  presetSlots[idx].size  = sz;
  presetSlots[idx].valid = true;
  for (int i = 0; i < 10; i++)
    presetSlots[idx].name[i] = (char)EEPROM.read(base + 2 + i);
  presetSlots[idx].name[9] = '\0';
  for (int i = 0; i < DUMP_MAX_SIZE; i++)
    presetSlots[idx].data[i] = EEPROM.read(base + 12 + i);
}

void eeSaveMeta() {
  eeWriteByte(EE_ADDR_MAGIC,   EE_MAGIC);
  eeWriteByte(EE_ADDR_COUNT,   (byte)presetCount);
  eeWriteByte(EE_ADDR_CURRENT, (byte)currentSlot);
}

bool eeLoad() {
  if (EEPROM.read(EE_ADDR_MAGIC) != EE_MAGIC) return false;
  presetCount = (int)EEPROM.read(EE_ADDR_COUNT);
  currentSlot = (int)EEPROM.read(EE_ADDR_CURRENT);
  if (presetCount < 0 || presetCount > MAX_PRESETS) presetCount = 0;
  if (currentSlot < 0 || currentSlot >= presetCount) currentSlot = 0;
  for (int i = 0; i < presetCount; i++) eeReadSlot(i);
  return true;
}

// =================== DUMP REQUEST ===================
const byte DUMP_REQUEST[] = { 0xF0, 0x42, 0x30, 0x1D, 0x10, 0xF7 };

// =================== RÉCEPTION MIDI ===================
const byte DUMP_HEADER[] = { 0xF0, 0x42, 0x30, 0x1D, 0x40 };
const int  HEADER_LEN    = 5;

byte rxBuffer[DUMP_MAX_SIZE];
int  rxLen       = 0;
bool rxInSysEx   = false;
int  rxHeaderPos = 0;

// =================== STRUCTURE POT ===================
struct PotConfig {
  int  pin;
  int  position;
  int  lastValue;
  int  physValue;
  int  candidate;
  int  stableCount;
  int  minVal;
  int  maxVal;
  const char* name;
  int  filteredRaw;
  bool caught;
  int  catchOffset; // position physique au moment de l'activation de la page
};

const int NUM_POTS  = 16;
const int NUM_PAGES = 5;

// --- Prototypes ---
void updateFiltered(PotConfig &pot);
int  getQuantized(PotConfig &pot);
void initFilter(PotConfig &pot);
void writeToBuffer(PotConfig &pot, int val);

// --------- Page 0 : I — Global & Niveaux ---------
PotConfig page0[NUM_POTS] = {
  {A0,  13, -1,-1,-1,0, 0, 7,   "Algo",   0,false,0},
  {A5,  14, -1,-1,-1,0, 0, 7,   "FeedB.", 0,false,0},
  {A8,  15, -1,-1,-1,0, 0, 3,   "LFOWave",0,false,0},
  {A12, 17, -1,-1,-1,0, 0, 255, "Rate",   0,false,0},
  {A1,  18, -1,-1,-1,0, 0, 127, "PMD",    0,false,0},
  {A4,  19, -1,-1,-1,0, 0, 7,   "PMS",    0,false,0},
  {A9,  20, -1,-1,-1,0, 0, 127, "AMD",    0,false,0},
  {A13, 21, -1,-1,-1,0, 0, 3,   "AMS",    0,false,0},
  {A2,  22, -1,-1,-1,0, 0, 7,   "M1Wave", 0,false,0},
  {A6,  23, -1,-1,-1,0, 0, 7,   "C1Wave", 0,false,0},
  {A10, 24, -1,-1,-1,0, 0, 7,   "M2Wave", 0,false,0},
  {A14, 25, -1,-1,-1,0, 0, 7,   "C2Wave", 0,false,0},
  {A3,  42, -1,-1,-1,0, 0, 127, "M1Lvl",  0,false,0},
  {A7,  43, -1,-1,-1,0, 0, 127, "C1Lvl",  0,false,0},
  {A11, 44, -1,-1,-1,0, 0, 127, "M2Lvl",  0,false,0},
  {A15, 45, -1,-1,-1,0, 0, 127, "C2Lvl",  0,false,0}
};

// --------- Page 1 : II — Enveloppes Attack/Decay/Sustain ---------
PotConfig page1[NUM_POTS] = {
  {A0,  46, -1,-1,-1,0, 0, 31, "M1Att.", 0,false,0},
  {A5,  47, -1,-1,-1,0, 0, 31, "C1Att.", 0,false,0},
  {A8,  48, -1,-1,-1,0, 0, 31, "M2Att.", 0,false,0},
  {A12, 49, -1,-1,-1,0, 0, 31, "C2Att.", 0,false,0},
  {A1,  50, -1,-1,-1,0, 0, 31, "M1Decy", 0,false,0},
  {A4,  51, -1,-1,-1,0, 0, 31, "C1Decy", 0,false,0},
  {A9,  52, -1,-1,-1,0, 0, 31, "M2Decy", 0,false,0},
  {A13, 53, -1,-1,-1,0, 0, 31, "C2Decy", 0,false,0},
  {A2,  54, -1,-1,-1,0, 0, 15, "M1Sust", 0,false,0},
  {A6,  55, -1,-1,-1,0, 0, 15, "C1Sust", 0,false,0},
  {A10, 56, -1,-1,-1,0, 0, 15, "M2Sust", 0,false,0},
  {A14, 57, -1,-1,-1,0, 0, 15, "C2Sust", 0,false,0},
  {A3,  58, -1,-1,-1,0, 0, 31, "M1Dec2", 0,false,0},
  {A7,  59, -1,-1,-1,0, 0, 31, "C1Dec2", 0,false,0},
  {A11, 60, -1,-1,-1,0, 0, 31, "M2Dec2", 0,false,0},
  {A15, 61, -1,-1,-1,0, 0, 31, "C2Dec2", 0,false,0}
};

// --------- Page 2 : III — Release, EG, Detune ---------
PotConfig page2[NUM_POTS] = {
  {A0,  62, -1,-1,-1,0, 0, 15, "M1Rel.", 0,false,0},
  {A5,  63, -1,-1,-1,0, 0, 15, "C1Rel.", 0,false,0},
  {A8,  64, -1,-1,-1,0, 0, 15, "M2Rel.", 0,false,0},
  {A12, 65, -1,-1,-1,0, 0, 15, "C2Rel.", 0,false,0},
  {A1,  74, -1,-1,-1,0, 0, 3,  "M1_EG",  0,false,0},
  {A4,  75, -1,-1,-1,0, 0, 3,  "C1_EG",  0,false,0},
  {A9,  76, -1,-1,-1,0, 0, 3,  "M2_EG",  0,false,0},
  {A13, 77, -1,-1,-1,0, 0, 3,  "C2_EG",  0,false,0},
  {A2,  34, -1,-1,-1,0, 0, 7,  "M1Det1", 0,false,0},
  {A6,  35, -1,-1,-1,0, 0, 7,  "C1Det1", 0,false,0},
  {A10, 36, -1,-1,-1,0, 0, 7,  "M2Det1", 0,false,0},
  {A14, 37, -1,-1,-1,0, 0, 7,  "C2Det1", 0,false,0},
  {A3,  38, -1,-1,-1,0, 0, 3,  "M1Det2", 0,false,0},
  {A7,  39, -1,-1,-1,0, 0, 3,  "C1Det2", 0,false,0},
  {A11, 40, -1,-1,-1,0, 0, 3,  "M2Det2", 0,false,0},
  {A15, 41, -1,-1,-1,0, 0, 3,  "C2Det2", 0,false,0}
};

// --------- Page 3 : IV — Multiply, AMS, Key Scale ---------
PotConfig page3[NUM_POTS] = {
  {A0,  26, -1,-1,-1,0, 0, 15, "M1Mul1", 0,false,0},
  {A5,  27, -1,-1,-1,0, 0, 15, "C1Mul1", 0,false,0},
  {A8,  28, -1,-1,-1,0, 0, 15, "M2Mul1", 0,false,0},
  {A12, 29, -1,-1,-1,0, 0, 15, "C2Mul1", 0,false,0},
  {A1,  30, -1,-1,-1,0, 0, 15, "M1Mul2", 0,false,0},
  {A4,  31, -1,-1,-1,0, 0, 15, "C1Mul2", 0,false,0},
  {A9,  32, -1,-1,-1,0, 0, 15, "M2Mul2", 0,false,0},
  {A13, 33, -1,-1,-1,0, 0, 15, "C2Mul2", 0,false,0},
  {A3,  70, -1,-1,-1,0, 0, 1,  "M1_AMS", 0,false,0},
  {A7,  71, -1,-1,-1,0, 0, 1,  "C1_AMS", 0,false,0},
  {A11, 72, -1,-1,-1,0, 0, 1,  "M2_AMS", 0,false,0},
  {A15, 73, -1,-1,-1,0, 0, 1,  "C2_AMS", 0,false,0},
  {A2,  66, -1,-1,-1,0, 0, 3,  "M1Scal", 0,false,0},
  {A6,  67, -1,-1,-1,0, 0, 3,  "C1Scal", 0,false,0},
  {A10, 68, -1,-1,-1,0, 0, 3,  "M2Scal", 0,false,0},
  {A14, 69, -1,-1,-1,0, 0, 3,  "C2Scal", 0,false,0}
};

// --------- Page 4 : V — Velocity, Track, Reverb, Rate ---------
PotConfig page4[NUM_POTS] = {
  {A0,  86, -1,-1,-1,0, 0, 15, "M1Velo", 0,false,0},
  {A5,  87, -1,-1,-1,0, 0, 15, "C1Velo", 0,false,0},
  {A8,  88, -1,-1,-1,0, 0, 15, "M2Velo", 0,false,0},
  {A12, 89, -1,-1,-1,0, 0, 15, "C2Velo", 0,false,0},
  {A1,  90, -1,-1,-1,0, 0, 15, "M1Trck", 0,false,0},
  {A4,  91, -1,-1,-1,0, 0, 15, "C1Trck", 0,false,0},
  {A9,  92, -1,-1,-1,0, 0, 15, "M2Trck", 0,false,0},
  {A13, 93, -1,-1,-1,0, 0, 15, "C2Trck", 0,false,0},
  {A3,  78, -1,-1,-1,0, 0, 1,  "M1Revb", 0,false,0},
  {A7,  79, -1,-1,-1,0, 0, 1,  "C1Revb", 0,false,0},
  {A11, 80, -1,-1,-1,0, 0, 1,  "M2Revb", 0,false,0},
  {A15, 81, -1,-1,-1,0, 0, 1,  "C2Revb", 0,false,0},
  {A2,  82, -1,-1,-1,0, 0, 7,  "M1Rate", 0,false,0},
  {A6,  83, -1,-1,-1,0, 0, 7,  "C1Rate", 0,false,0},
  {A10, 84, -1,-1,-1,0, 0, 7,  "M2Rate", 0,false,0},
  {A14, 85, -1,-1,-1,0, 0, 7,  "C2Rate", 0,false,0}
};

PotConfig*  pages[NUM_PAGES] = { page0, page1, page2, page3, page4 };
const char* pageNames[NUM_PAGES] = { "I", "II", "III", "IV", "V" };
// =================== LEDS ===================
const int LED_PREV     = 12; // s'allume brièvement quand on clique page −
const int LED_NEXT     = 11; // s'allume brièvement quand on clique page +
const int LED_DUMP_REQ = 10; // clignote pendant un Dump Request
const int LED_SLOT     = 9;  // fixe = chargement dump / clignote = sauvegarde

// Timers et états LED
unsigned long ledPrevTimer    = 0;
bool          ledPrevOn       = false;
const unsigned long LED_BRIEF = 300; // durée allumage bref (ms)

unsigned long ledNextTimer    = 0;
bool          ledNextOn       = false;

int           ledDumpReqBlink = 0;   // demi-périodes restantes (0=arrêté)
unsigned long ledDumpReqTimer = 0;
bool          ledDumpReqState = false;

// ledSlotBlink : 0=éteint, -1=fixe allumé, >0=clignote N demi-périodes
int           ledSlotBlink    = 0;
unsigned long ledSlotTimer    = 0;
bool          ledSlotState    = false;

int         currentPage = 0;
PotConfig*  pots = page0;
int         lastMovedPot = -1;

// =============== DÉFILEMENT AUTO ===============
unsigned long lastScrollTime        = 0;
const unsigned long SCROLL_INTERVAL = 3000;
int           currentDisplayGroup   = 0;
bool          autoScrollEnabled     = true;

// =================== BOUTONS ===================
// Pin 7 : page − / Pin 8 : page +
const int BTN_PAGE_PREV = 7;
const int BTN_PAGE_NEXT = 8;

bool          prevLastState         = HIGH;
bool          prevCurrentState      = HIGH;
unsigned long prevDebounceTime      = 0;

bool          nextLastState         = HIGH;
bool          nextCurrentState      = HIGH;
unsigned long nextDebounceTime      = 0;

// Pin 5 : cycle dumps (court) / sauvegarde (long)
const int CYCLE_BUTTON_PIN = 5;

bool          cycleButtonLastState  = HIGH;
bool          cycleButtonState      = HIGH;
unsigned long cyclePressStartTime   = 0;
bool          cyclePressActive      = false;
bool          cycleLongPressHandled = false;
unsigned long cycleLastDebounceTime = 0;

// Pin 6 : Dump Request (long)
const int DUMP_BTN_PIN = 6;
bool          dumpBtnLastState      = HIGH;
bool          dumpBtnState          = HIGH;
unsigned long dumpBtnPressStart     = 0;
bool          dumpBtnActive         = false;
bool          dumpBtnLongHandled    = false;
unsigned long dumpBtnDebounceTime   = 0;
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
void loop() {

  // --- Réception MIDI ---
  receiveMidi();

  // --- Timeout Dump Request ---
  if (waitingForDump && (millis() - dumpRequestTime > DUMP_TIMEOUT)) {
    waitingForDump = false;
    stopLedDumpReq();
    showMessage("Pas de reponse", "Verif. MIDI IN");
    delay(1000);
    updateDisplay();
  }

  // --- Bouton page − (pin 7) ---
  {
    int r = digitalRead(BTN_PAGE_PREV);
    if (r != prevLastState) prevDebounceTime = millis();
    if ((millis() - prevDebounceTime) > debounceDelay) {
      if (r != prevCurrentState) {
        prevCurrentState = r;
        if (prevCurrentState == LOW) {
          flashLedPrev();
          setPage((currentPage - 1 + NUM_PAGES) % NUM_PAGES);
        }
      }
    }
    prevLastState = r;
  }

  // --- Bouton page + (pin 8) ---
  {
    int r = digitalRead(BTN_PAGE_NEXT);
    if (r != nextLastState) nextDebounceTime = millis();
    if ((millis() - nextDebounceTime) > debounceDelay) {
      if (r != nextCurrentState) {
        nextCurrentState = r;
        if (nextCurrentState == LOW) {
          flashLedNext();
          setPage((currentPage + 1) % NUM_PAGES);
        }
      }
    }
    nextLastState = r;
  }

  // --- Bouton cycle pin 5 : court=naviguer, long=sauvegarder ---
  {
    int r = digitalRead(CYCLE_BUTTON_PIN);
    if (r != cycleButtonLastState) cycleLastDebounceTime = millis();
    if ((millis() - cycleLastDebounceTime) > debounceDelay) {
      if (r != cycleButtonState) {
        cycleButtonState = r;
        if (cycleButtonState == LOW) {
          cyclePressStartTime   = millis();
          cyclePressActive      = true;
          cycleLongPressHandled = false;
        } else {
          // Tout relachement AVANT que l'appui long (3 s) ne se declenche fait
          // passer au slot suivant. Auparavant la fenetre etait limitee a
          // SHORT_PRESS_TIME (500 ms) : un appui un peu trop long ne faisait
          // rien du tout, d'ou l'impression qu'il fallait cliquer plusieurs
          // fois. La sauvegarde reste protegee par cycleLongPressHandled.
          if (cyclePressActive && !cycleLongPressHandled) {
            if (presetCount > 0) {
              loadSlot((currentSlot + 1) % presetCount);
            } else {
              showMessage("Aucun dump stocke", "Appui long 6=Dump");
              delay(800);
              updateDisplay();
            }
          }
          cyclePressActive = false;
        }
      }
    }
    cycleButtonLastState = r;

    // Détection appui long pin 5
    if (cyclePressActive && !cycleLongPressHandled) {
      if ((millis() - cyclePressStartTime) >= LONG_PRESS_SAVE) {
        cycleLongPressHandled = true;
        saveCurrentDump();
      }
    }
  }

  // --- Bouton pin 6 : court = Dump Request, maintenu = supprimer ---
  {
    int r = digitalRead(DUMP_BTN_PIN);
    if (r != dumpBtnLastState) dumpBtnDebounceTime = millis();
    if ((millis() - dumpBtnDebounceTime) > debounceDelay) {
      if (r != dumpBtnState) {
        dumpBtnState = r;
        if (dumpBtnState == LOW) {
          dumpBtnPressStart  = millis();
          dumpBtnActive      = true;
          dumpBtnLongHandled = false;
          delPrompted        = false;
        } else {
          // Relachement : si l'appui long n'a pas deja agi, c'est un Dump Request.
          if (dumpBtnActive && !dumpBtnLongHandled) {
            if (delPrompted) { delPrompted = false; updateDisplay(); }
            waitingForDump  = true;
            dumpRequestTime = millis();
            rxLen           = 0;
            rxInSysEx       = false;
            startLedDumpReq();
            showMessage("Dump Request...", "En attente Z3");
            sendDumpRequest();
          }
          dumpBtnActive = false;
          delPrompted   = false;
        }
      }
    }
    dumpBtnLastState = r;

    // Maintien : invite puis suppression
    if (dumpBtnActive && !dumpBtnLongHandled) {
      unsigned long tenu = millis() - dumpBtnPressStart;
      if (!delPrompted && tenu >= DELETE_PROMPT_MS && presetCount > 0) {
        delPrompted = true;
        if (slotEstUsine(currentSlot)) {
          showMessage("Usine - protege", presetSlots[currentSlot].name);
        } else {
          showMessage("Supprimer ?", presetSlots[currentSlot].name);
        }
      }
      if (tenu >= DELETE_HOLD_MS) {
        dumpBtnLongHandled = true;
        delPrompted        = false;
        if (presetCount > 0) deleteCurrentPreset();
      }
    }
  }

  // --- Gestion LEDs ---
  updateLeds();

  // --- Défilement automatique OLED ---
  // Suspendu pendant l'invite de suppression : il rafraichit l'ecran toutes
  // les 3 s et l'effacerait en pleine lecture.
  if (autoScrollEnabled && !delPrompted) {
    if (millis() - lastScrollTime >= SCROLL_INTERVAL) {
      lastScrollTime = millis();
      currentDisplayGroup = (currentDisplayGroup + 1) % 4;
      updateDisplay();
    }
  }

  // --- Potentiomètres ---
  if (sendBufferSize == 0) return;
  if (millis() - lastSendTime < DELAY_MS) return;

  for (int i = 0; i < NUM_POTS; i++) {
    updateFiltered(pots[i]);
    int newPhys = getQuantized(pots[i]);

    // --- MODE PICKUP : zone morte relative ---
    // Au changement de page/preset, caught=false et catchOffset=physValue snapshot.
    // Le pot est ignoré jusqu'à ce qu'il ait bougé d'au moins CATCH_STEPS paliers
    // depuis sa position initiale. Cela évite les faux positifs sans exiger de
    // traverser une valeur précise — la sensibilité reste maximale.
    if (!pots[i].caught) {
      int steps    = pots[i].maxVal + 1;
      int width    = 1024 / steps;
      int raw_step = constrain(pots[i].filteredRaw / width, 0, pots[i].maxVal);
      // Nombre de paliers à franchir avant activation (2 = ~2/maxVal de la course)
      const int CATCH_STEPS = 2;
      if (abs(raw_step - pots[i].catchOffset) >= CATCH_STEPS) {
        pots[i].caught    = true;
        pots[i].physValue = raw_step;
        pots[i].candidate = raw_step;
        // Ne pas écraser lastValue ici : le pot devient actif mais la prochaine
        // validation par stabilité déclenchera l'envoi si la valeur est différente.
      } else {
        pots[i].physValue = raw_step; // suivi silencieux
      }
      continue;
    }

    // Validation par stabilité adaptative
    const int stableNeeded = (pots[i].maxVal >= 127) ? 8 : 6;

    if (newPhys != pots[i].candidate) {
      pots[i].candidate   = newPhys;
      pots[i].stableCount = 1;
    } else {
      pots[i].stableCount++;
      if (pots[i].stableCount >= stableNeeded) {
        if (newPhys != pots[i].physValue) {
          pots[i].physValue   = newPhys;
          pots[i].lastValue   = newPhys;
          writeToBuffer(pots[i], newPhys);
          lastMovedPot        = i;
          currentDisplayGroup = i / 4;
          lastScrollTime      = millis();
          autoScrollEnabled   = true;
          needToSend          = true;
        }
        pots[i].stableCount = 0;
      }
    }
  }

  if (needToSend) {
    sendSysEx();
    lastSendTime = millis();
    needToSend   = false;
    updateDisplay();
  }
}

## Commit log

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2026-06-05 Add KiCad hardware reconstruction + 4067 mux / remote-pot jack / RC filter mod
    Reverse-engineered the SysEx Patcher board (baritonomarchetto, CC BY-NC-SA) from
    its Gerbers into a KiCad schematic + PCB, with 6N138 MIDI-IN confirmed by copper
    tracing. Adds a CD74HC4067 analog mux (extra analog input on a 6.35mm remote-pot
    jack + spare channels) and RC anti-noise filters (1k + 100nF) on every analog input.
    [SysEx_Patcher.kicad_pcb, SysEx_Patcher.kicad_sch]
2026-06-05 hardware: fully route the PCB (4 layers + GND plane)
    Re-placed for routability (each RC filter beside its pot, 4067 inside the
    board) and autorouted: 130/130 connections routed, DRC clean (no unconnected,
    shorts, clearance or courtyard violations). 4-layer stackup with a GND plane.
    Only cosmetic silkscreen-text overlaps remain.
    [SysEx_Patcher.kicad_pcb]
2026-06-05 hardware: compact board to 212x180mm, rounded corners, + fab Gerbers
    Trimmed the board and added 5mm rounded corners (Edge.Cuts arcs). Re-routed
    clean on the smaller outline (130/130 nets, DRC clean apart from cosmetic silk).
    Added the fabrication package: 4-layer Gerbers + Excellon drill + job file
    (hardware/fab/ and SysEx_Patcher_GERBERS.zip), ready for JLCPCB.
    [SysEx_Patcher-B_Cu.gbr, SysEx_Patcher-B_Mask.gbr, SysEx_Patcher-B_Silkscreen.gbr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]
2026-06-05 hardware: real pluggable Arduino Mega 2560 shield (THT, fully routed)
    Re-laid out as a true stackable shield: Mega connectors at the exact Arduino
    Mega 2560 header positions (two rows 48.26mm apart, pinout derived from the
    original copper, analog A0..A15 order verified) so the Mega plugs underneath.
    Layout: inputs (MIDI in/out, jack, DC) on top, 16 pots in a 4x4 grid each with
    its RC filter alongside, 4 push buttons in a vertical column, LEDs on the right,
    Mega header block at the bottom. 100% THT, 4 layers + GND plane, fully routed
    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
    [SysEx_Patcher-B_Cu.gbr, SysEx_Patcher-B_Mask.gbr, SysEx_Patcher-B_Silkscreen.gbr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]
2026-06-05 hardware: real MIDI DIN-5 + 6.35mm jack footprints on the shield
    Replaced placeholder connectors with proper footprints: custom MIDI DIN-5 180deg
    footprint (geometry taken from the original board's drill, vertical) in a project
    library, and the vertical Neutrik 6.35mm TRS jack (T/R/S) for the remote-pot jack.
    Reorganized the top connector area and re-routed: fully routed (0 unconnected),
    DRC clean except 1 trivial track-to-mounting-pad clearance to nudge by hand.
    Gerbers updated; added project fp-lib-table + SysEx_Patcher.pretty.
    [SysEx_Patcher-B_Cu.gbr, SysEx_Patcher-B_Mask.gbr, SysEx_Patcher-B_Silkscreen.gbr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]
2026-06-05 hardware: re-sync schematic to the shield PCB
    Regenerated the schematic from the shield's exact component list (Mega header
    strips JMA/JMD, custom MIDI DIN-5 + Neutrik jack symbols/footprints, CD74HC4067
    mux, RC filters). Refs/nets/footprints now match the .kicad_pcb (86 common refs,
    0 ERC errors), so 'Update PCB from Schematic' is consistent again.
    [SysEx_Patcher.kicad_sch]
2026-06-06 hardware: fix connector orientations + horizontal jack, reroute clean
    - MIDI DIN-5 (J1/J2): rebuild footprint to match original PCB orientation
    (mount holes at top, signal arc below, data pins 4/5 lowest) — was upside down
    - 6.35mm jack (J10): switch to Neutrik NRJ6HF-1 horizontal, nose toward the top
    edge so the cable plugs in horizontally from the top (was vertical NJ3FD-V)
    - DC barrel (J3): rotate 270deg so the opening faces the top edge like the
    other inputs (was facing left)
    - OLED (J5): plain 1x4 header, no pin-name silkscreen
    - move 4067 mux + jack RC filter into the gap between the two Mega header rows
    to declutter the dense analog header row (fixes autorouter A15/D10 short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
    [SysEx_Patcher-B_Cu.gbl, SysEx_Patcher-B_Cu.gbr, SysEx_Patcher-B_Mask.gbr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]
2026-06-06 hardware: fix 6.35mm jack orientation (nose now faces the top edge)
    The NRJ6HF-1 opening is on the footprint +x side (Sleeve pad nearest the
    opening, Tip deepest). The previous 270deg rotation pointed the threaded nose
    DOWN into the board; rotate to 90deg so the nose protrudes past the TOP edge and
    the cable plugs in horizontally from the top. Reroute: 0 unconnected, DRC clean;
    regenerate fab Gerbers + previews.
    [SysEx_Patcher-B_Cu.gbl, SysEx_Patcher-B_Mask.gbs, SysEx_Patcher-B_Silkscreen.gbo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]
2026-06-06 hardware: OLED header J5 rotated 90deg + silkscreen pin labels (GND/VCC/SCL/SDA)
    J5 now sits as a horizontal 1x4 row with each pin labelled on the silkscreen
    (GND, VCC, SCL, SDA) above its pad. Reroute: 0 unconnected, DRC clean;
    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
    [SysEx_Patcher-B_Cu.gbl, SysEx_Patcher-B_Mask.gbs, SysEx_Patcher-B_Silkscreen.gbo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]
2026-06-06 hardware: restore drill file (fab/SysEx_Patcher.drl) dropped from fab folder
    The standalone drill file was accidentally removed and not re-copied in the
    last exports (copy glob missed the no-hyphen filename). The zip already
    contained the correct drill; this re-adds the loose .drl to match.
    [SysEx_Patcher.drl]
2026-06-06 hardware: battery header J4 rotated 90deg + silk pin labels (GND/+5V/GND/VIN)
    Relocated J4 below the DC jack so its horizontal row doesn't wall off the OLED
    SDA/SCL escape path. Reroute: 0 unconnected, DRC clean; fab Gerbers + previews
    regenerated. (drill file copy now includes the no-hyphen .drl)
    [SysEx_Patcher-B_Cu.gbl, SysEx_Patcher-B_Mask.gbs, SysEx_Patcher-B_Silkscreen.gbo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]
2026-06-06 hardware: add polarised 100uF electrolytic (C19) on the +5V rail
    - C19 = CP_Radial D6.3mm electrolytic across +5V/GND (pad1 + -> +5V, pad2 - -> GND)
    with silkscreen polarity '+' marker and 100uF value label
    - schematic: C19 uses Device:C_Polarized symbol
    - reroute 0 unconnected, DRC clean, ERC clean (only the 14 intentional spare
    mux-channel warnings); fab Gerbers, schematic PDF, previews + BOM updated
    [SysEx_Patcher-B_Cu.gbl, SysEx_Patcher-B_Mask.gbs, SysEx_Patcher-B_Silkscreen.gbo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]
2026-06-06 hardware: move 4067 mux (U2) beside the Mega + align board within sheet frame
    - U2 (and R27/C18) relocated to the free area to the RIGHT of the Arduino Mega
    instead of sitting in the gap between the header rows (i.e. under the Mega)
    - shift all board geometry by (20,20) so the PCB sits inside the KiCad drawing
    sheet frame instead of hanging off the page corner
    - reroute: 0 unconnected, DRC clean; fab Gerbers + previews regenerated
    [SysEx_Patcher-B_Cu.gbl, SysEx_Patcher-B_Mask.gbs, SysEx_Patcher-B_Silkscreen.gbo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]
2026-06-06 hardware: add "MIDI IN"/"MIDI OUT" silkscreen labels on J1/J2
    Reroute 0 unconnected, DRC clean; fab Gerbers + previews regenerated.
    [SysEx_Patcher-B_Cu.gbl, SysEx_Patcher-B_Mask.gbs, SysEx_Patcher-B_Silkscreen.gbo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]
2026-06-06 hardware: clean, fully-wired schematic (organized by functional block)
    Replace the flat label-on-pin schematic with a readable single-sheet design:
    - components grouped into titled blocks (power, MIDI IN/OUT, jack, buttons,
    LEDs, OLED, mux, Mega headers, 16 pot RC filters)
    - power symbols (+5V/GND) and net labels on wired stubs
    - each of the 16 pots drawn as a wired RC filter cell (pot -> 1k series ->
    100nF to GND, wiper + ADC node labelled)
    - ERC clean except the 14 intentional spare 4067 mux-channel labels
    [SysEx_Patcher.kicad_pcb, SysEx_Patcher.kicad_sch]
2026-06-06 hardware: remove SW1 prog/MIDI switch, wire 6N138 -> RX0 directly
    The 6N138 output (open-collector + 10k pull-up R5) is now hardwired to RX0 (D0)
    instead of through the SPDT prog/MIDI switch. MIDI IN works permanently; only
    caveat is not flashing firmware while MIDI is actively streaming in. Reroute:
    0 unconnected, DRC clean; schematic + fab Gerbers + docs updated.
    [SysEx_Patcher-B_Cu.gbl, SysEx_Patcher-B_Mask.gbs, SysEx_Patcher-B_Silkscreen.gbo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]
2026-06-06 hardware: compact shield — Mega now sits UNDER the pots (like the original)
    - pot row pitch 24mm so the two Mega header rows tuck into the gaps between pot
    rows (analog y72, digital y120); the Mega plugs underneath the pot grid
    - board shrinks 172x228 -> 172x172
    - mux 4067 + jack filter relocated below the pot grid (clear of the Mega)
    - MIDI-out resistors R2/R3 moved to clear the raised pot-filter column
    - footprint courtyards stripped (stacked board: components legitimately sit over
    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
    [SysEx_Patcher-B_Cu.gbl, SysEx_Patcher-B_Mask.gbs, SysEx_Patcher-B_Silkscreen.gbo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]
2026-06-06 hardware: fix Mega-under-pots layout — header rows now clear of pot bodies
    The pot footprint body extends ~13mm above its origin (not the 7mm pin span),
    so the header rows were landing under the pot bodies. Fixes:
    - RC filters made horizontal (beside the pot) so each row is shorter
    - header rows recentred in the real gaps between pot BODIES (analog y66, digital y114)
    - routing clearance bumped to 0.25mm to clear a track/mounting-pad near-miss
    Reroute: 0 unconnected, DRC clean. Board 172x172, Mega plugs under the pot grid.
    [SysEx_Patcher-B_Cu.gbl, SysEx_Patcher-B_Mask.gbs, SysEx_Patcher-B_Silkscreen.gbo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]
2026-06-06 hardware: shift button column left to clear Mega digital header pins
    SW2-SW5 moved from x=10 to x=6 (board x30->x26) so SW4 no longer crowds
    the JMD1 digital header row. Re-routed (0 unconnected), DRC clean of
    electrical violations, gerbers/drill/previews regenerated.
    [SysEx_Patcher-B_Cu.gbl, SysEx_Patcher-B_Mask.gbs, SysEx_Patcher-B_Silkscreen.gbo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]
2026-06-06 schematic: add Arduino Mega 2560 block symbol + outward net labels
    Replaced the 7 abstract shield-header connectors (JMA1-3/JMD1-4) with a
    single Arduino Mega 2560 symbol: A0-A15 on the left, RX0/D0..SCL/D21 on
    the right, 5V/VIN on top, GND on bottom, every Mega net clearly labelled.
    Signal net labels now always render outward (fixes the CD74HC4067 labels
    that overlapped the body). Added a title block. ERC: 0 errors.
    [SysEx_Patcher.kicad_sch]
2026-06-06 schematic: fully wired clean .sch (point-to-point wiring per block)
    Rebuilt the schematic layout so components are connected with real wires
    instead of floating net labels: each functional block (power, MIDI in/out,
    jack, buttons, LEDs, OLED, mux, 16 pot RC cells) is wired point-to-point;
    local nets are named, power via +5V/GND symbols, and only long-haul signals
    to the Arduino Mega go through net labels. Added a project symbol library
    (SysEx_Patcher.kicad_sym + sym-lib-table) so the custom Mega 2560 symbol
    resolves. ERC: 0 errors (14 intentional spare MUX_CH2-15 warnings).
    [SysEx_Patcher.kicad_sch]
2026-06-07 Spec: passage SysEx Patcher en vrai shield Mega 2560 + 3 boutons/3 LEDs
2026-06-07 Plan d'implémentation : passage SysEx Patcher en vrai shield Mega + 3 boutons/3 LEDs
2026-07-26 presets: ajoute FlutAtk (flûte sensible à l'attaque) + passage en PROGMEM
    Le Flute__1 d'usine du Z3 n'a de Velocity Int que sur C-2, une PORTEUSE :
    la vélocité n'y fait varier que le volume, jamais le timbre. C'est pourquoi
    il ne répond pas à l'attaque de la guitare, contrairement à SynLead qui en
    a sur les modulateurs M-1 et M-2.
    FlutAtk reprend le dump réel du Z3 et n'en change que six octets : le nom,
    et la Velocity Int des deux modulateurs portée à 8. L'équilibre des niveaux,
    les enveloppes et les rapports de fréquence sont intacts — ce sont eux qui
    font le caractère doux. Dosable en direct sur la page V, potentiomètres
    M1Velo et M2Velo.
    Les tableaux passent en PROGMEM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
    [KorgZ3_SysEx_08-05-2026.ino]
2026-07-26 presets: complète les presets usine manquants sur une EEPROM déjà peuplée
    Le chargement usine ne s'exécutait que si l'EEPROM était vierge. Sur un
    appareil ayant déjà servi — SynLead et HiString enregistrés — le bloc était
    sauté et FlutAtk n'apparaissait jamais. C'est le cas signalé par l'utilisateur.
    Au démarrage, chaque preset usine absent est désormais ajouté à la suite,
    sans toucher aux presets existants ni à leur ordre. La présence se teste sur
    le champ nom du dump (octets 5 à 12), celui-là même dont extractName() dérive
    le nom des slots : un preset usine déjà installé, ou une version que
    l'utilisateur a modifiée et resauvegardée sous le même nom, n'est p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
    [KorgZ3_SysEx_08-05-2026.ino]
2026-07-27 presets: suppression par 7+8 maintenus, presets usine protégés
    Il n'existait aucun moyen d'effacer un preset : saveCurrentDump() ajoute
    toujours un slot, d'où les doublons après une nouvelle sauvegarde.
    SUPPRESSION — broches 7 et 8 maintenues 2 s. Ces deux boutons n'ont aucune
    action en appui long, il n'y a donc rien à neutraliser. Le maintien fait
    office de confirmation : le nom visé s'affiche pendant l'appui, relâcher
    avant la fin annule.
    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
2026-07-27 Corrige trois défauts d'ergonomie des boutons
    INVITE DE SUPPRESSION ILLISIBLE. Le défilement automatique rafraîchit l'écran
    toutes les 3 s et effaçait le « Supprimer ? » en pleine lecture. Il est
    suspendu pendant la combinaison.
    CHANGEMENT DE PAGE PARASITE. Presser 7 puis 8 appelait setPage() deux fois,
    et chaque appel réinitialise les 16 potentiomètres (8 lectures espacées d'une
    milliseconde) — environ 130 ms, donc un quart de seconde de boucle bloquée
    pour revenir au point de départ. Le changement est désormais ignoré si
    l'autre bouton est déjà enfoncé, et la page d'avant la combinaison est
    restaurée si l'un des deux a eu le temps d'agir.
    DÉFILEMENT PIN 5 CAPRICIEUX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
    [KorgZ3_SysEx_08-05-2026.ino]
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
